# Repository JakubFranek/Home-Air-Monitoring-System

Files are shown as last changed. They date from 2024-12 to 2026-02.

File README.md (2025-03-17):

# Home Air Monitoring System

**Home Air Monitoring System (HAMS)** is my personal hardware & embedded software development project designed to monitor indoor and outdoor air quality in my home.

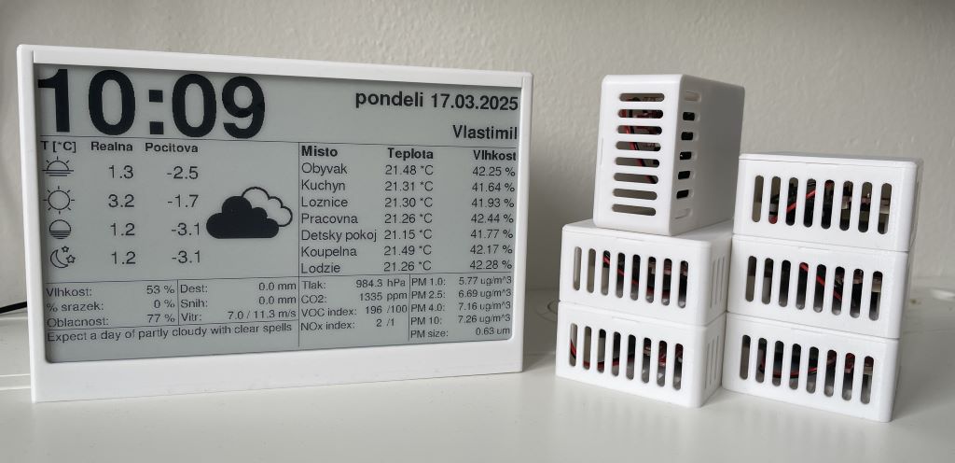
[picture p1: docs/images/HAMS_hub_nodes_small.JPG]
HAMS hub and nodes


## Overview

The system consists of a [**central hub**](./docs/hub.md) and [**six wireless sensor nodes**](./docs/node.md) to measure:

- Temperature
- Relative Humidity
- Atmospheric Pressure
- Particulate Matter
- Volatile Organic Compounds (VOCs)
- NOₓ
- CO₂

## System Components

- **Central Hub**
   - **ESP32-based**; mains-powered.
   - Connects to the internet for weather updates and time synchronization via SNTP.
   - Displays real-time measurements on a 7.5" 800x480 e-ink screen with a 1 minute refresh rate.
   - Contains sensors for all previously listed quantities.
   - Screen-sized 3D-printed enclosure (estimated 175 mm x 92.65 mm x 120 mm).

- **Sensor Nodes**
   - **STM32-based** and battery-powered, optimized for low power consumption and long battery life.
   - Equipped with temperature and humidity sensors only, with optional hardware support for one more sensor.
   - Transmit data to the hub every minute using nRF24 radio modules.
   - Minimalistic and visually non-intrusive 3D-printed case with a small form factor (estimated 81 mm x 58 mm x 28 mm).

## Sensors

- **SHT40**
   - Temperature and humidity sensor from Sensirion.
   - Used in the central hub and sensor nodes.
   - Temperature accuracy: ±0.2 °C
   - Humidity accuracy: ±1.8 %RH
- **SCD41**
   - CO2 sensor from Sensirion.
   - Used in the central hub.
   - CO2 accuracy: ±50 ppm ± 5.0 %m.v. (depending on range)
- **SGP41**
   - VOC and NOx gas index sensor from Sensirion.
   - Used in the central hub.
- **SPS30**
   - Particulate matter sensor from Sensirion.
   - Used in the central hub.
   - Accuracy: ±10 %
- **BME280**
   - Temperature, relative humidity and atmospheric pressure sensor from Adafruit.
   - Used in the central hub (for atmospheric pressure only).
   - Atmospheric pressure accuracy: ±1 hPa

## Documentation

- [Hub](./docs/hub.md)
- [Nodes](./docs/node.md)
- [SHT4x calibration](./docs/sht4x_calibration.md)

## Repository Structure

```plaintext
├── docs                         # Documentation for project setup, usage, etc.
├── utilities                    # Various auxiliary scripts, tools etc.
│   ├── sht_sensor_burn_in       # PlatformIO Arduino project for SHT40 sensor burn-in
│   └── sht_sensor_calibration   # PlatformIO Arduino project for SHT40 sensor calibration
├── hub
│   ├── hardware                 # PCB design and schematic for hub
│   ├── firmware                 # Firmware for the ESP32-based central hub
│   └── 3D_models                # 3D models for the hub's enclosure
├── node
│   ├── firmware                 # Firmware for the STM32-based sensor nodes
│   ├── hardware                 # PCB designs and schematics for nodes
│   └── 3D_models                # 3D models for the nodes' enclosures
├── README.md                    # Project overview (you are reading this now!)
└── TODO.md                      # Project task list

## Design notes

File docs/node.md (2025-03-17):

# HAMS node

HAMS node firmware for STM32L031K6 MCU is written in C and uses LL (low-layer) library as provided by ST Microelectronics, using no OS.

The nRF24 and SHT4x drivers are identical to the ones used in the ESP32 based HAMS hub, as all device drivers in this project are platform independent.

The MCU runs at 8 MHz (internal high speed oscillator), as the wake time is not determined by the MCU itself but rather by the sensor and the nRF24 module.

## Debug mode

Pressing the STATUS button on the PCB will toggle the debug mode on and off. When debug mode is on, the following effects occur:
1. debug log messages are sent via UART to the 2x7 1.27 mm pin header (accessible via ST-LINK V3 MINIE) at 38400 baud rate (because of this, the program runs slower and the wake time is longer)
2. green status LED is on (drawing up to 2 mA)
3. if there was any error since the last successfully completed loop cycle, the red error LED is on (drawing up to 2 mA)

Example UART output debug log messages are below:

```
[handle_state_sleep]woke up due to RTC: state = 0, app_status = 0, nrf24_status = 0, sht4x_status = 0, event = 4
[app_loop]: state = 1, app_status = 0, nrf24_status = 0, sht4x_status = 0, event = 0
[app_loop]: state = 2, app_status = 0, nrf24_status = 0, sht4x_status = 0, event = 0
[app_loop]: state = 3, app_status = 0, nrf24_status = 0, sht4x_status = 0, event = 0
[app_loop]: state = 4, app_status = 0, nrf24_status = 0, sht4x_status = 0, event = 0
[app_loop]: state = 0, app_status = 0, nrf24_status = 0, sht4x_status = 0, event = 0
[handle_state_sleep]entering sleep: state = 0, app_status = 0, nrf24_status = 0, sht4x_status = 0, event = 0
```

## Program flow

The application code structure is an event-driven Finite State Machine (FSM). The simplified flowchart is below.

The RTC peripheral is configured to wake up the node once every 60 seconds.

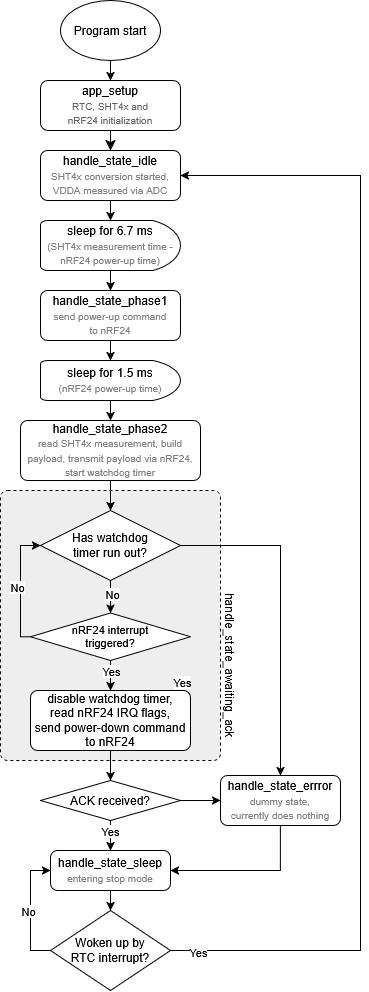
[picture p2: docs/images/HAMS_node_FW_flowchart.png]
HAMS node FW flowchart


## Logic analyzer waveforms

Typical period between stop mode exit and entrance is less than 15 ms.

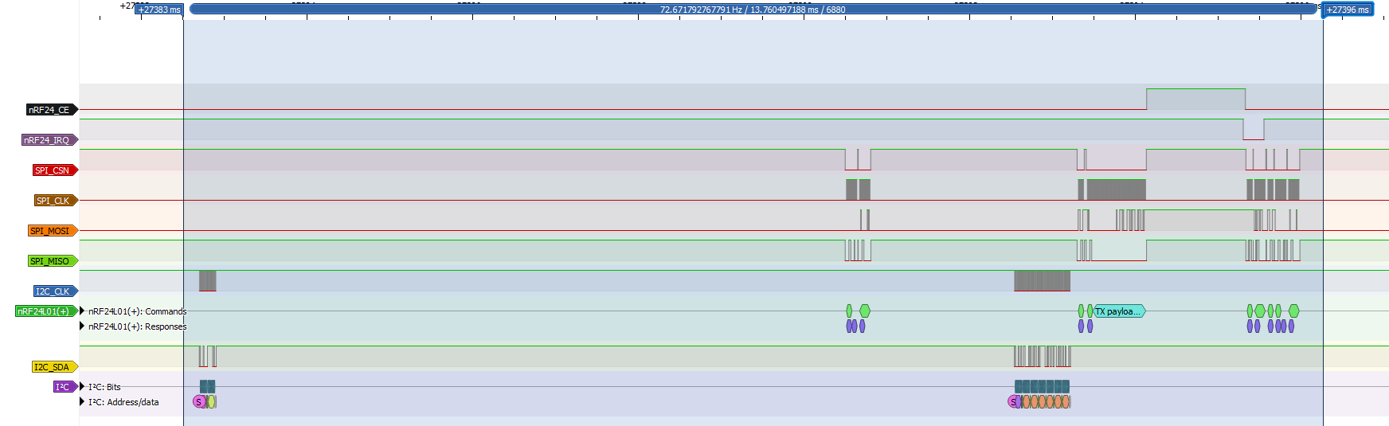
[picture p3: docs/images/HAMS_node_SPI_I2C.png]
HAMS node logic analyzer waveforms


## Batteries and power consumption

The nodes are powered via CR2032 batteries, with a nominal voltage of 3 Volt and nominal capacity of 210 mAh.

Typical current draw in stop mode has been measured to be from 1.8 to 2.5 uA, where cca half of the consumption is due to MCU and the other half is due to the nRF24 module (SHT4x current in power down is typically 80 nA per datasheet).

To calculate average power consumption, let us make the following conservative assumptions:
- MCU draws 5 mA when not in stop mode
- SHT4x draws 500 uA when measuring
- SHT4x takes up to 8.3 ms to measure (typical 6.9 ms per datasheet)
- nRF24 module draws 12 mA when transmitting (typical 11.3 mA per datasheet) and 400 uA when active but not transmitting (typical current draw during startup per datasheet)
- transmitting takes up to 1 ms (typical less than 0.5 ms)
- total wake time is 15 ms

Under the above assumptions, the average power consumption is 4.12 uA and the battery life is 5.8 years.

## Hardware

Case dimensions are: 81 mm (L) x 58 mm (W) x 30 mm (H). Printed by Prusa MK4S 3D-printer, using Prusament PLA Pristine White filament.

### PCB front
HAMS node PCB front

### PCB back
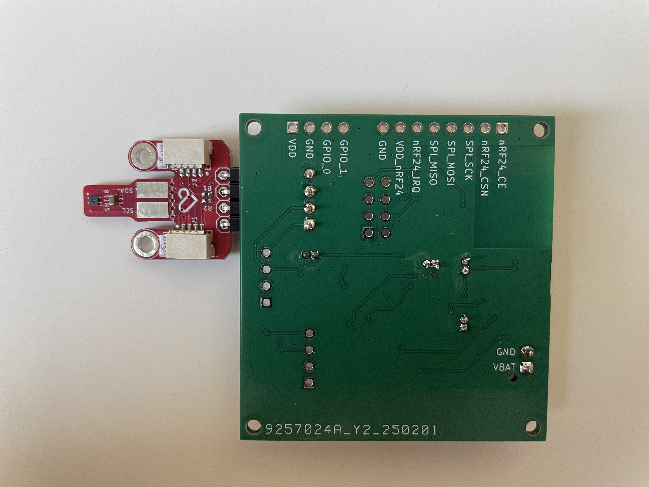
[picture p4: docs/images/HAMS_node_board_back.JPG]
HAMS node PCB back


### Disassembled
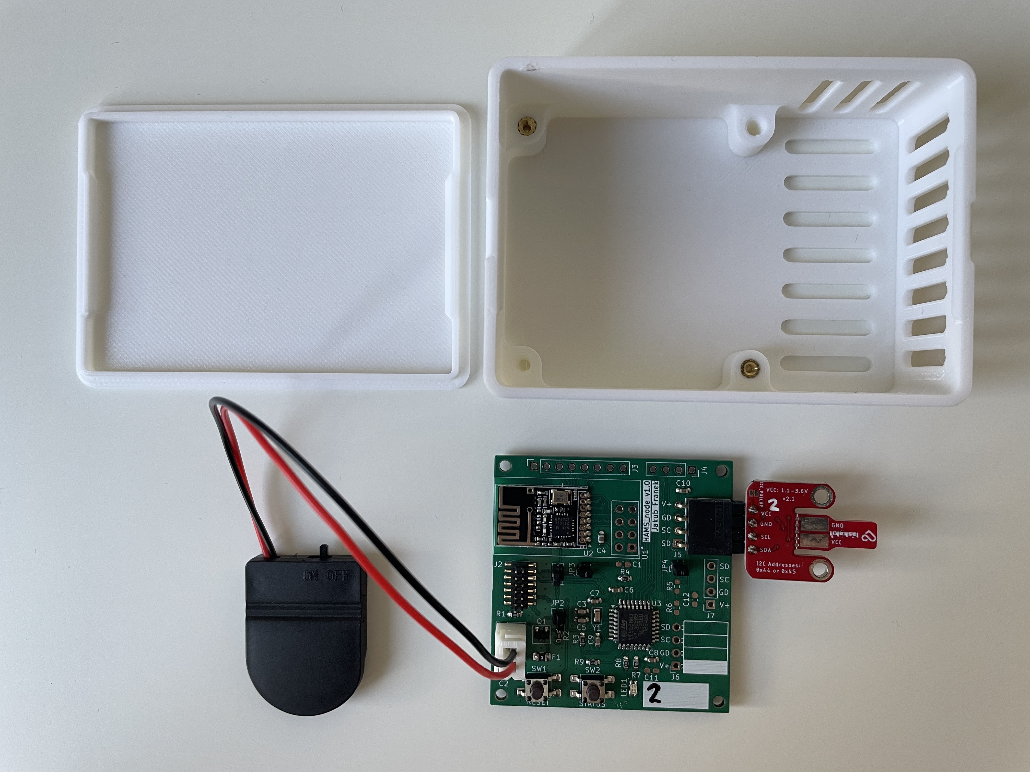
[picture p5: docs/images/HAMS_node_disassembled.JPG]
HAMS node disassembled


### Assembled box internals
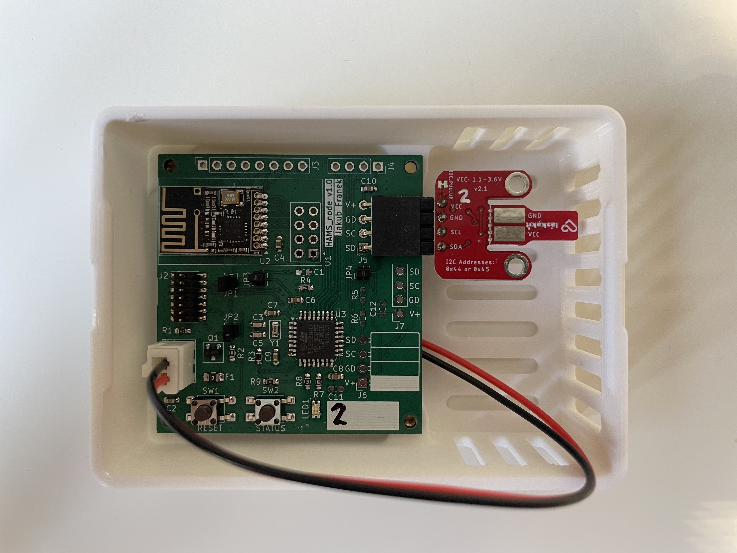
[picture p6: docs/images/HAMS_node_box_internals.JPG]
HAMS node box internals


### Assembled box front
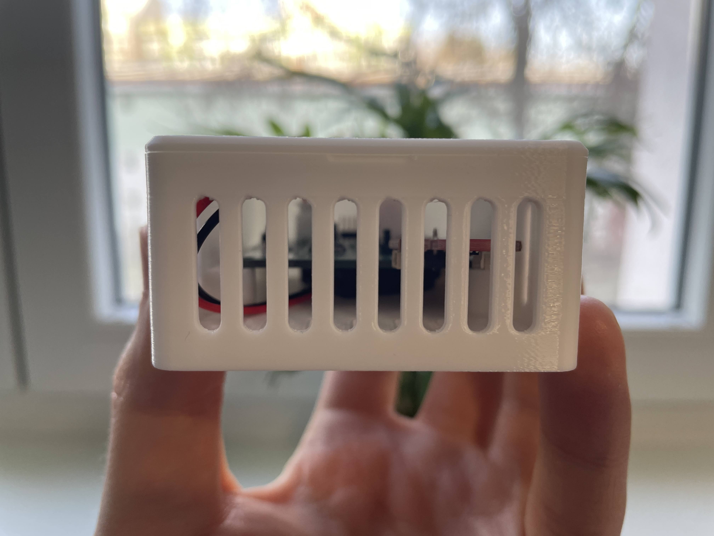
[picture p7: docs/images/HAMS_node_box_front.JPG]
HAMS node box front


### Assembled box bottom
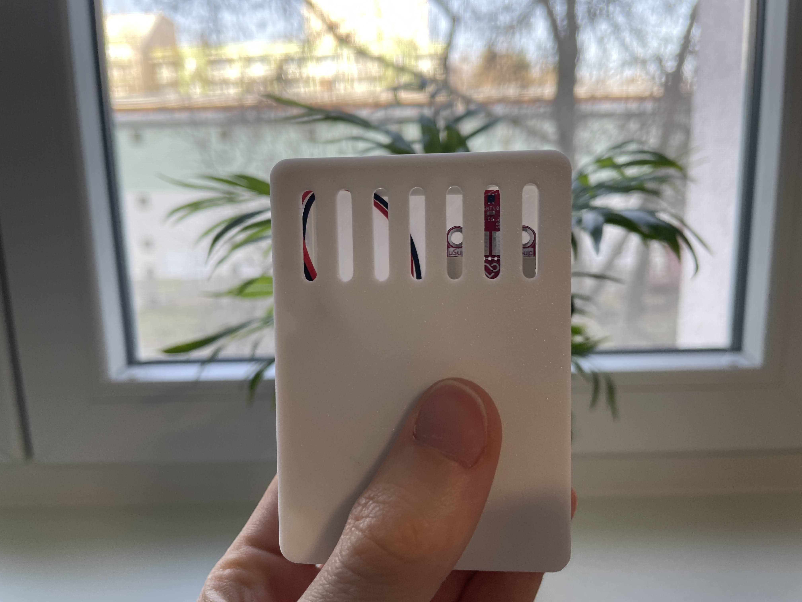
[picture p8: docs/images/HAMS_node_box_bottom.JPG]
HAMS node box bottom


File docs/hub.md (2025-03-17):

# HAMS hub

HAMS hub firmware for ESP32-S3 module is written in C and C++ and uses FreeRTOS as provided by Espressif.

The C++ language is used for the display-related code, as the CalEPD component (and its dependency Adafruit-GFX) are C++ based and utilize classes. Due to this the main file must also be a C++ file. Everything else is in plain C.

ESP32 is a chip with two CPU cores (the APP_CPU and the PRO_CPU). The PRO_CPU runs the task responsible for communication with the nRF24 radio module, whiile the APP_CPU handles everything else.

The nRF24 and SHT4x drivers are identical to the ones used in the STM32 based HAMS node, as all device drivers in this project are platform independent.

## Debug button

The debug button is located on the back of the HAMS hub enclosure, next to the reset button.

Pressing and releasing the button for more than 300 ms but less than 2 seconds will toggle the debug mode on and off. When debug mode is on, the display immediately changes to the [debug view](#debug-mode), which lists internal debug info.

Pressing and releasing the button after more than 2 seconds will schedule a SCD41 re-calibration (FRC). In the next SCD41 measurement cycle, the SCD41 will be recalibrated, assuming the current CO2 concentration is 425 ppm.

## Program flow

The application code flow is visualized in a simplified flowchart below.

Please note not all sensors take a reading every main loop cycle. For example SCD41 (CO₂ sensor) takes a reading once every 5 cycles / minutes.

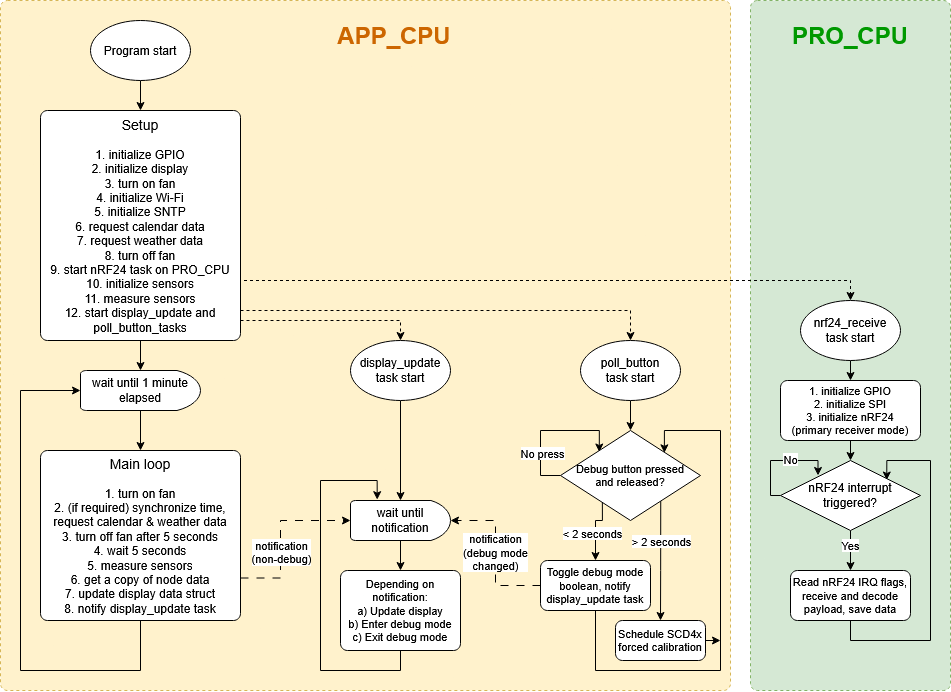
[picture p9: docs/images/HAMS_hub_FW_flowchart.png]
HAMS hub FW flowchart


## Hardware

Case dimensions are: 175 mm (W) x 92.85 mm (L) x 118 mm (H). Printed by Prusa MK4S 3D-printer, using Prusament PLA Pristine White filament.

### Front
HAMS hub front normal

### Debug mode
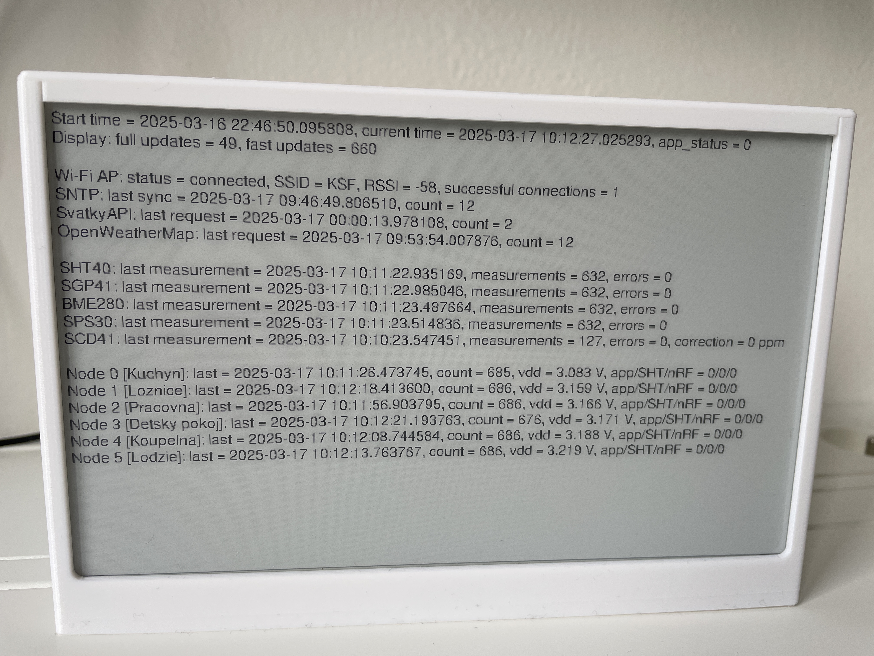
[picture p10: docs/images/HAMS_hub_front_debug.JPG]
HAMS hub front debug


### Start-up logging
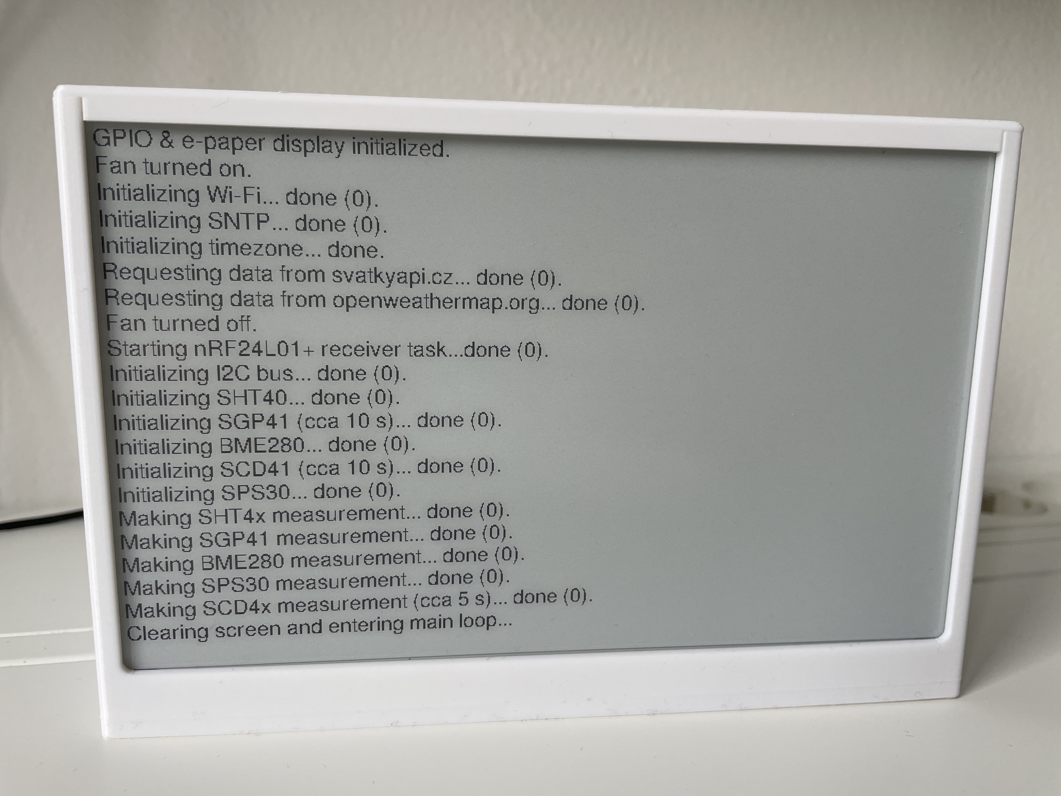
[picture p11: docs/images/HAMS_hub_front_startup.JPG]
HAMS hub front startup


### Side shot 1
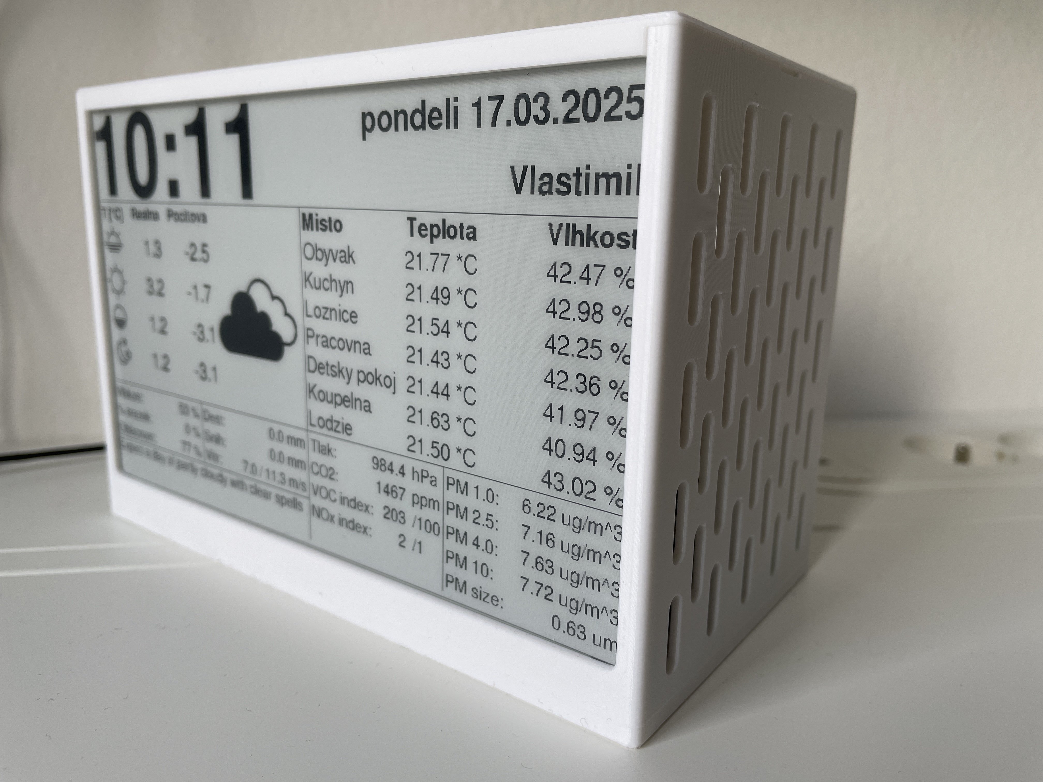
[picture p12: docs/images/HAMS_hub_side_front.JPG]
HAMS hub side front


### Side shot 2
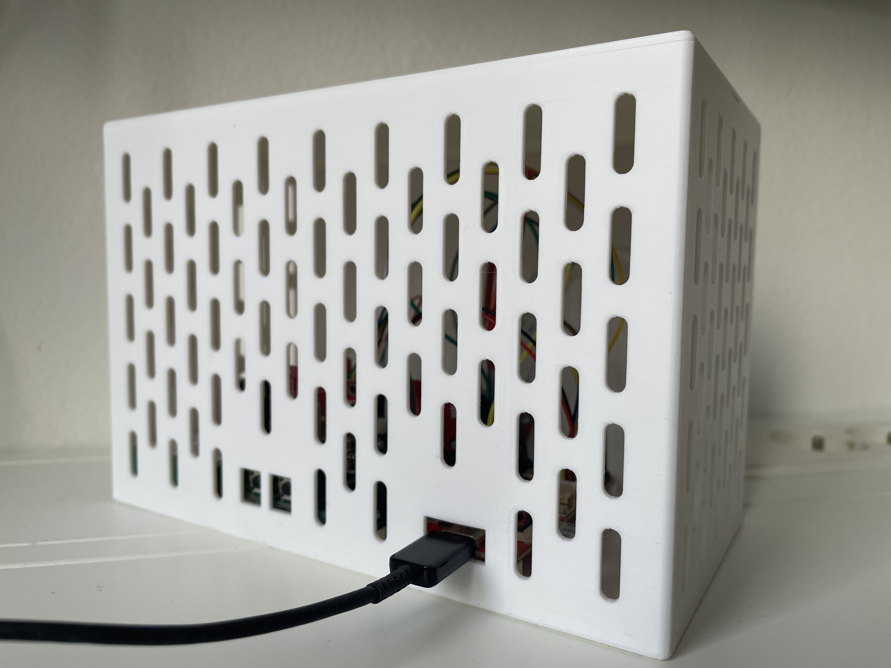
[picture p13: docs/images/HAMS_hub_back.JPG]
HAMS hub side back


### Internals
HAMS hub internals

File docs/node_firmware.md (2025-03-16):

# HAMS node firmware

HAMS node firmware for STM32L031K6 MCU is written in C and uses LL (low-layer) library as provided by ST Microelectronics, using no OS.

The nRF24 and SHT4x drivers are identical to the ones used in the ESP32 based HAMS hub, as all device drivers in this project are platform independent.

## Debug mode

Pressing the STATUS button on the PCB will toggle the debug mode on and off. When debug mode is on, the following effects occur:
1. debug log messages are sent via UART to the 2x7 1.27 mm pin header (accessible via ST-LINK V3 MINIE) at 38400 baud rate
2. green status LED is on
3. if there was any error since the last successfully completed loop cycle, the red error LED is on

## Program flow

The application code structure is an event-driven Finite State Machine (FSM). The simplified flowchart is below.

HAMS node FW flowchart

## Logic analyzer waveforms

Typical period between stop mode exit and entrance is less than 15 ms.

HAMS node logic analyzer waveforms

## Batteries and power consumption

The nodes are powered via CR2032 batteries, with a nominal voltage of 3 Volt and nominal capacity of 210 mAh.

Typical current draw in stop mode has been measured to be 1.8 to 2.5 uA.

To calculate average power consumption, let us make the following conservative assumptions:
- the MCU draws 5 mA when not in stop mode
- the nRF24 module draws 15 mA when transmitting
- transmitting takes up to 2 ms
- total wake time is 15 ms

Under the above assumptions, the average power consumption is 3.74 uA and the battery life is 6.4 years.

## Hardware

Case dimensions are: 81 mm (L) x 58 mm (W) x 30 mm (H). Printed by Prusa MK4S 3D-printer, using Prusament PLA Pristine White filament.

### PCB front
HAMS node PCB front

### PCB back
HAMS node PCB back

### Disassembled
HAMS node disassembled

### Assembled box internals
HAMS node box internals

### Assembled box front
HAMS node box front

### Assembled box bottom
HAMS node box bottom

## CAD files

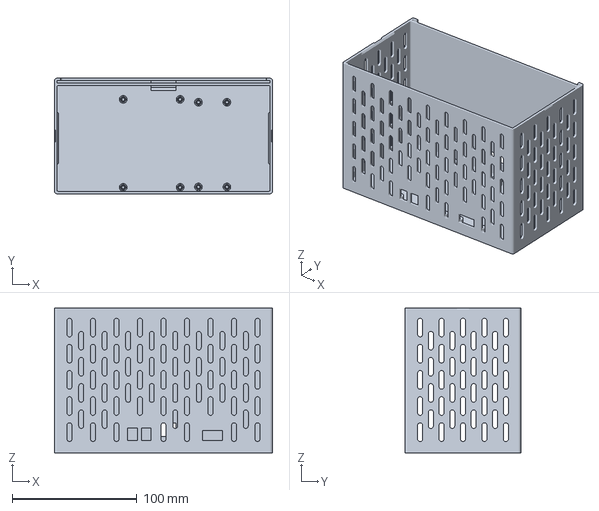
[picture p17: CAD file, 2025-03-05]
hub/3D_models/HAMS_hub_case.3mf
175.0 x 92.8 x 116.0 mm

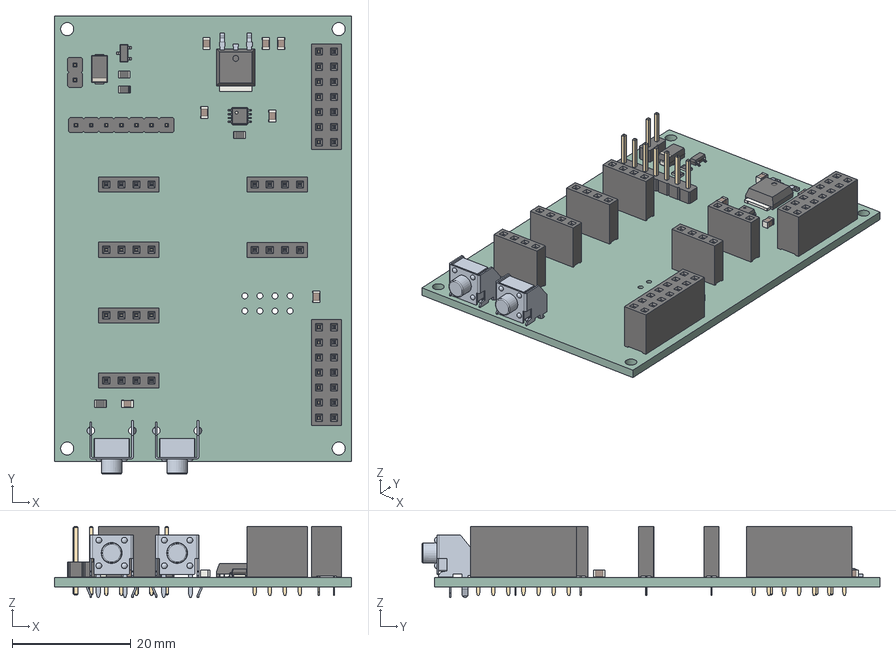
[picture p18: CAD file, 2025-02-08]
hub/hardware/HAMS_hub/HAMS_hub.step
50.0 x 77.1 x 12.0 mm
SOT_23
root x 2
PinSocket_2x07_P2.54mm_Vertical x 2
R_0805_2012Metric x 4
PinSocket_1x04_P2.54mm_Vertical x 6
PinHeader_1x02_P254mm_Vertical
C_0805_2012Metric x 7
SSOP_8_295x28mm_P065mm
D_SMA
PinHeader_1x07_P254mm_Vertical
CQ assembly
HAMS_hub_PCB

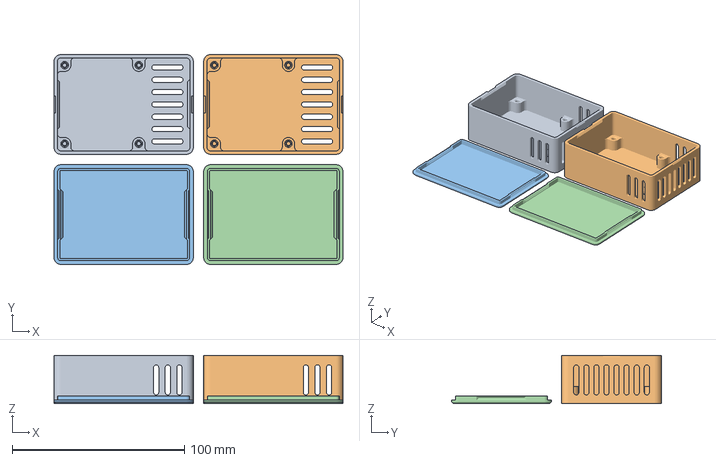
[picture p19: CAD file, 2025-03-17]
node/3D_models/HAMS_node_case_small_x2.3mf
168.0 x 122.0 x 28.0 mm
HAMS_node_case_small.stl
HAMS_node_case_small_cover.stl

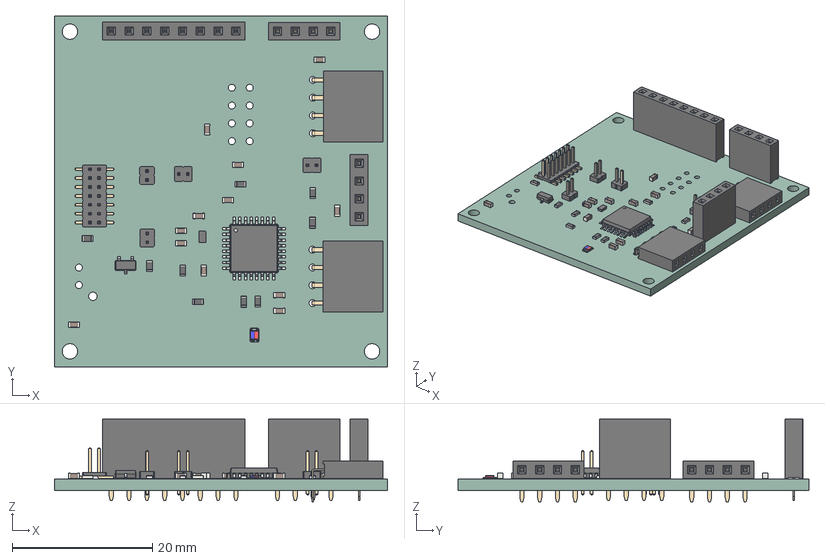
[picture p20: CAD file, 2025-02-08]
node/hardware/HAMS_node/HAMS_node.step
47.5 x 50.0 x 11.8 mm
PinHeader_1x02_P127mm_Vertical x 4
C_0603_1608Metric x 12
MicroCrystal_CM9V_T1A
R_0603_1608Metric x 9
PinSocket_1x04_P2.54mm_Horizontal x 2
PinSocket_1x04_P2.54mm_Vertical x 2
LQFP_32_7x7mm_P08mm
APHBM2012QBDSURKC
SOT_23
PinSocket_1x08_P2.54mm_Vertical
PinHeader_2x07_P127mm_Vertical_SMD
HAMS_node_PCB

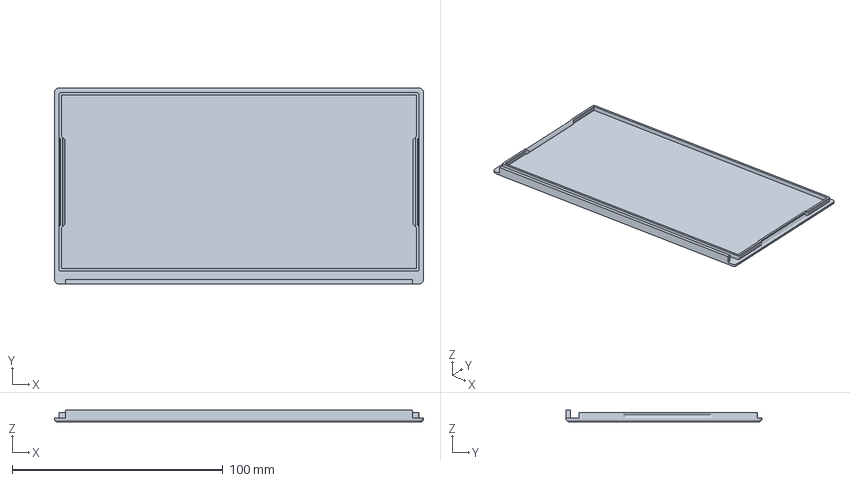
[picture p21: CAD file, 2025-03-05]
hub/3D_models/HAMS_hub_cover.3mf
175.0 x 92.8 x 5.80 mm

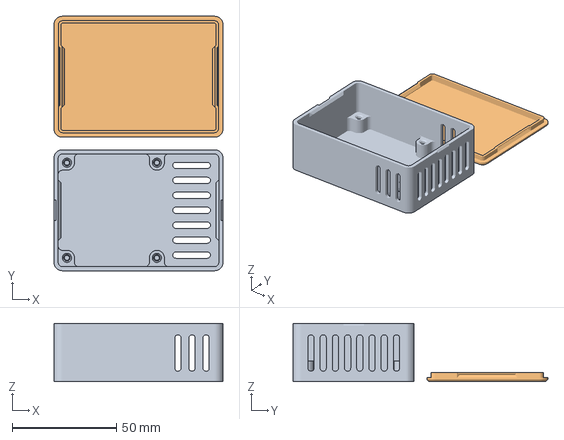
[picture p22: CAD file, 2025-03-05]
node/3D_models/HAMS_node_case_small.3mf
81.0 x 122.0 x 28.0 mm
HAMS_node_case_small.stl
HAMS_node_case_small_cover.stl

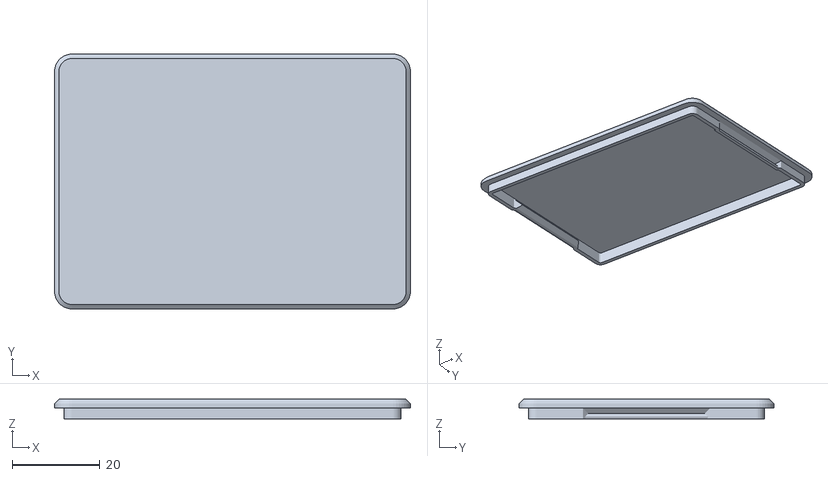
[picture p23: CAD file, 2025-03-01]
node/3D_models/HAMS_node_case_small_cover.stl
81.0 x 58.0 x 4.50

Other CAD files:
hub/3D_models/HAMS_hub_cover.stl
node/3D_models/HAMS_node_case_small.stl

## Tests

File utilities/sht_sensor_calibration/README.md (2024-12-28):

# Temperature & Relative Humidity Sensor Calibration

The purpose of this PlatformIO-based Arduino Uno project is to take temperature & relative humidity readings using many sensors, some which will be used in the HAMS hub and nodes, in order to calibrate them.

The measured data is sent via UART to the PC serial monitor, as well as displayed on a 20x4 alphanumeric LCD display, which is useful when the calibration setup is in an airtight transparent box, powered by a battery.

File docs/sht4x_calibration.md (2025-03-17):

# SHT4x reconditioning and calibration

The Sensirion SHT4x temperature and humidity sensors are calibrated in the factory. However, during assembly their accuracy is negatively affected by volatile organic compounds (VOCs). This impacts humidity measurement the most.

The image below shows a table. The numbered SHT40 sensors are clearly contaminated as they all report 6-9 % higher relative humidity than others.

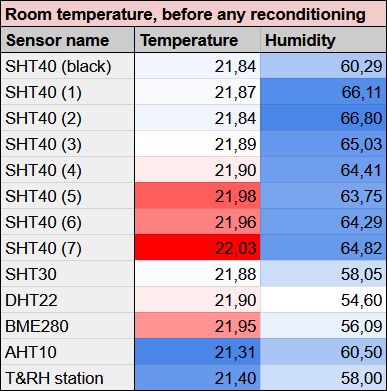
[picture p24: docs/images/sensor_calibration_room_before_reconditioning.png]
Sensor measurements, room, before reconditioning


Reconditioning has been performed using the on-chip heater, using [this a Arduino PlatformIO program](../utilities/sht_sensor_burn_in/src/main.cpp). As shown in the image below, the systematic offset decreased to cca 3-4 %, but some remanent offset remained nonetheles. While most of the sensors achieved self-reported temperature higher than 100 °C during the reconditioning, some sensors were not able to reach temperature higher than 85 °C.

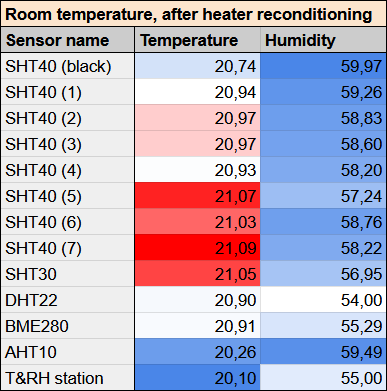
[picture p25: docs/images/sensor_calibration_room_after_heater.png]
Sensor measurements, room, after heater reconditioning


Final reconditioning has been performed using temperature forcing equipment (105 °C for cca 12 hours). The results are shown below.

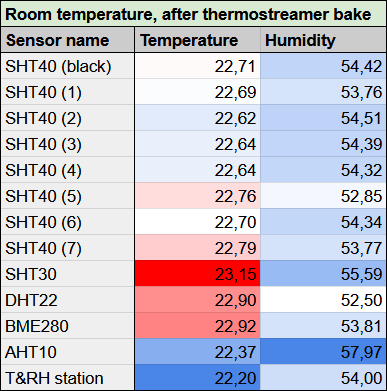
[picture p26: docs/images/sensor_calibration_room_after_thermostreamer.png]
Sensor measurements, room, after thermostreamer


To verify accuracy, the sensors were placed in a transparent airtight box and driven by [another Arduino PlatformIO program](../utilities/sht_sensor_calibration/src/main.cpp) powered from a powerbank. A bowl with a salt solution has been placed inside the box to produce known humidity (NaCl for 75 % and MgCl2 for 33 %). The measured quantities have been read from an LCD screen inside the box. 

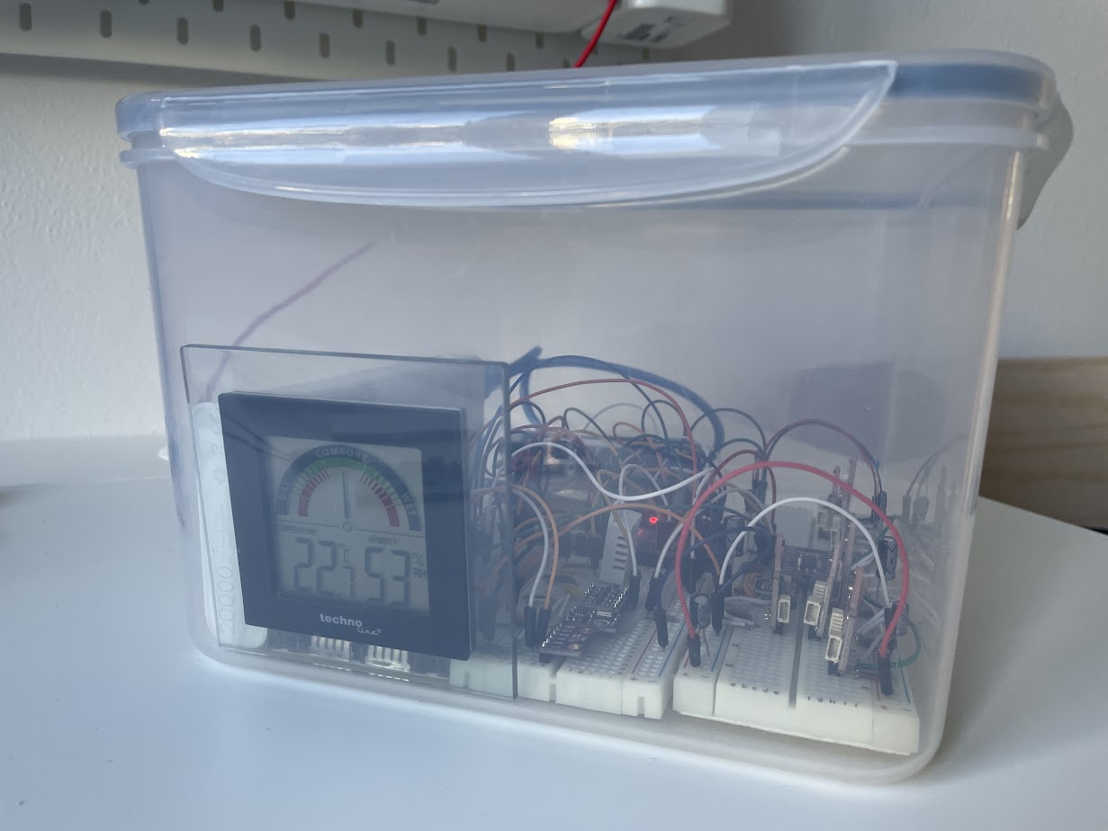
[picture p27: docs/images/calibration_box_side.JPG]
Calibration box, side


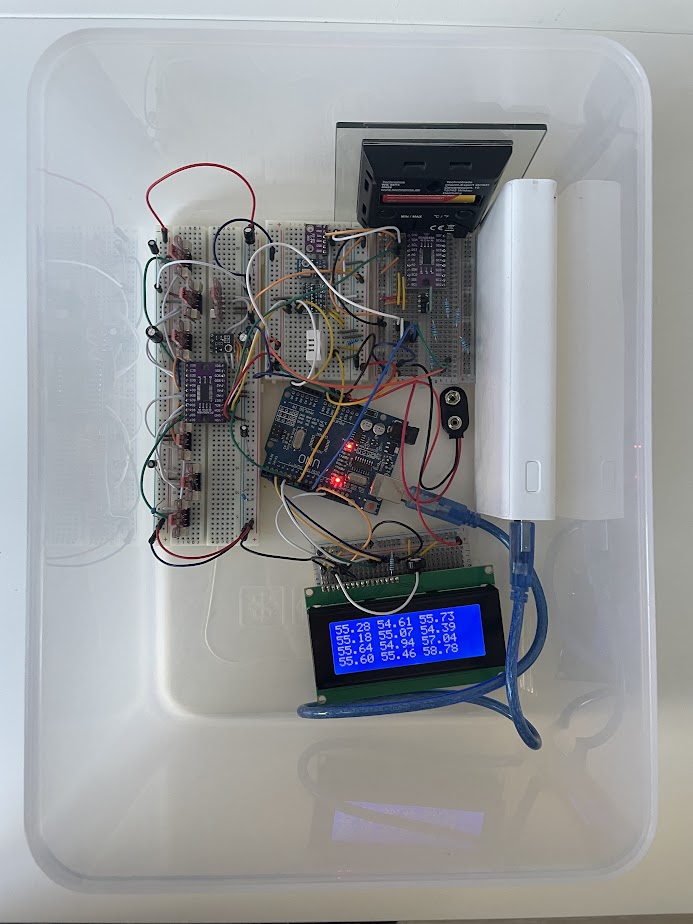
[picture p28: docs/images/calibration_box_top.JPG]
Calibration box, top


The results are shown below.

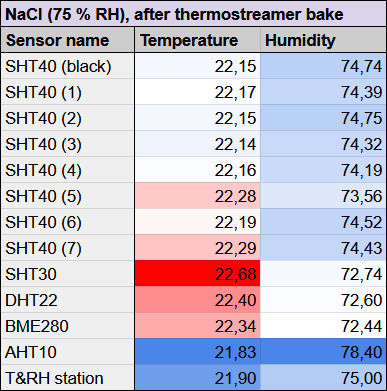
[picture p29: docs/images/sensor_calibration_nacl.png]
Sensor measurements, NaCl


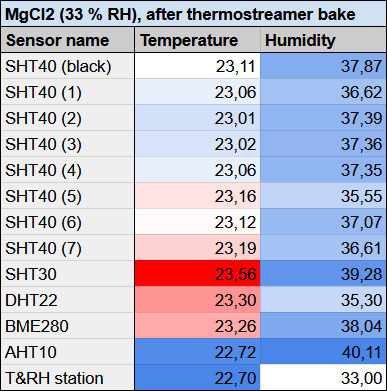
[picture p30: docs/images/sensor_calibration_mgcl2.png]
Sensor measurements, MgCl2


The NaCl measurements show that the sensors are undervaluing the relative humidity on average by less than 1 % (with the exception of sensor no.5), while the during the MgCl2 measurements the sensors overvalued the humidity by around 4 %. This remaining error has to be calibrated out in post-processing code (currently not implemented).

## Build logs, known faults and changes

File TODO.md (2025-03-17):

# Task list <!-- omit from toc -->

This is a task list for the HAMS project.

## Contents <!-- omit from toc -->
- [Work in progress](#work-in-progress)
- [To do](#to-do)
- [Backlog](#backlog)
- [Done](#done)

## Work in progress

## To do

## Backlog

- [ ] Hub firmware
    - [ ] Upload data from hub to Google Sheets or elsewhere online
    - [ ] Replace Adafruit_GFX with C-based graphical library to remove C++ altogether
    - [ ] Software calibration of SHT4x measurements
    - [ ] Turn SPS30 off after measurements to limit fan noise
- [ ] Node firmware
    - [ ] Support for SCD41 (possibly with MCU-driven ASC to minimize consumption)
    - [ ] Better error handling (nRF24 transmission of error codes even if FSM steps fail before nRF24 transmit step)
- [ ] Recalibrate SHT4x sensors

## Done

- [x] Node firmware v0.1
    - [x] Test firmware components in separate projects
        - [x] [Create and test nRF24L01+ driver](https://github.com/JakubFranek/STM32/tree/master/NUCLEO-L031K6/nRF24L01p_TX_RX_L031K6_LL)
        - [x] [Create and test SHT40 driver, incl. utilizing dedicated HW for CRC verification](https://github.com/JakubFranek/STM32/tree/master/NUCLEO-L031K6/SHT40_L031K6_LL) 
        - [x] [Test stop mode (incl. current consumption measurement)](https://github.com/JakubFranek/STM32/tree/master/NUCLEO-L031K6/Stop_mode_L031K6_LL)
        - [x] [Test ADC usage for supply voltage measurement](https://github.com/JakubFranek/STM32/tree/master/NUCLEO-L031K6/ADC_LL_L031K6)
        - [x] [Test scheduled wake-up from low power mode using RTC](https://github.com/JakubFranek/STM32/tree/master/NUCLEO-L031K6/RTC_wakeup_L031K6_LL)
    - [x] [Assemble all firmware components into one codebase](https://github.com/JakubFranek/Home-Air-Monitoring-System/tree/master/node/firmware/STM32L031K6)

- [x] Hub firmware v0.1
    - [x] Test firmware components in separate projects
        - [x] [Create and test SGP41 driver](https://github.com/JakubFranek/ESP32/tree/master/ESP-ink/I2C_SGP41)
        - [x] [Create and test SPS30 driver](https://github.com/JakubFranek/ESP32/tree/master/ESP-ink/I2C_SPS30)
        - [x] [Test nRF24L01+ driver (RX mode), incl. IRQ handling](https://github.com/JakubFranek/ESP32/tree/master/ESP-ink/nRF24L01p_RX)
        - [x] [Test SHT40 driver](https://github.com/JakubFranek/ESP32/tree/master/ESP-ink/I2C_SHT40)
        - [x] [Create and test SCD41 driver](https://github.com/JakubFranek/ESP32/tree/master/ESP-ink/I2C_SCD41)
        - [x] [Create and test BME280 driver](https://github.com/JakubFranek/ESP32/tree/master/ESP-ink/I2C_BME280)
        - [x] [Test 5 Volt fan control via GPIO](https://github.com/JakubFranek/ESP32/tree/master/ESP-ink/Fan_Switch)
        - [x] [Test WiFi connection](https://github.com/JakubFranek/ESP32/tree/master/Examples/station)
        - [x] [Test RTC time synchronization using SNTP](https://github.com/JakubFranek/ESP32/tree/master/Examples/sntp)
        - [x] [Combine WiFi connection and SNTP time sync into one code](https://github.com/JakubFranek/ESP32/tree/master/ESP-ink/WIFI_SNTP)
        - [x] Create e-ink display driver
            - [x] Determine best graphical library to use (Adafruit_GFX)
            - [x] Determine best driver to use ([customized CalEPD](https://github.com/JakubFranek/ESP32/tree/master/ESP-ink/Epaper_GDEY029T94_CalEPD_Demo))
            - [x] [Create and test GDEY075T7 driver](https://github.com/JakubFranek/ESP32/tree/master/ESP-ink/Epaper_GDEY075T7_CalEPD_Demo)
                - [x] Add support for full partial display refresh
                - [x] Test drawing a bitmap image
        - [x] [Get and parse current name day using HTTPS API](https://github.com/JakubFranek/ESP32/tree/master/ESP-ink/API_svatkyapicz)
        - [x] [Get and parse openweathermap.org weather forecast using HTTPS API](https://github.com/JakubFranek/ESP32/tree/master/ESP-ink/API_openweathermap)
    - [x] Design display interface
        - [x] Create display interface layout ([implemented in GDEY075T7 test project](https://github.com/JakubFranek/ESP32/tree/master/ESP-ink/Epaper_GDEY075T7_CalEPD_Demo))
        - [x] [Prepare a set of weather icon byte arrays for openweatherapi weather codes](https://github.com/JakubFranek/ESP32/blob/master/ESP-ink/Epaper_GDEY075T7_CalEPD_Demo/main/weather_icons.h)
        - [x] [Prepare a set of small morning / day / eve / night icons for temperatures](https://github.com/JakubFranek/ESP32/blob/master/ESP-ink/Epaper_GDEY075T7_CalEPD_Demo/main/time_of_day_icons.h)
    - [x] [Assemble all firmware components together into one codebase](https://github.com/JakubFranek/Home-Air-Monitoring-System/tree/master/hub/firmware)
        - [x] Implement e-ink display driver
        - [x] Implement WiFi connectivity
        - [x] Implement SNTP
        - [x] Implement svatkyapi.cz requests
        - [x] Implement openweathermap.org requests
        - [x] Implement SHT40 driver
        - [x] Implement SCD41 driver
        - [x] Implement SGP41 driver
        - [x] Implement SPS30 driver
        - [x] Implement BME280 driver
        - [x] Implement fan control
        - [x] Implement nRF24L01+ driver
        - [x] Display sensor data
        - [x] Display weather data
        - [x] Display startup sequence debug info
        - [x] Implement node timestamp checking
        - [x] Implement 24h minimum temperature logic for particular node
        - [x] Implement logic for long holiday names
        - [x] Implement debug display view based on GPIO button toggle
        - [x] Clean up code
        - [x] Show sensor status codes in debug mode
  
- [x] Node firmware
    - [x] Handle fault where nRF24 does not activate IRQ after transmitting
    - [x] Update SHT4x drivers (reuse better hub versions)
    - [x] Update nRF24 drivers (reuse better hub versions)
    - [x] Add comments / function documentation to app.c and important code elsewhere
    - [x] Add define for automatic retransmit delay based on NODE_ID
    - [x] Send UART debug logs only when in debug mode

- [x] Hub hardware
    - [x] Decide which connector to use to provide 5 Volt power to ESPink, SCD41, SPS30 and fan (ESPink hacked to provide 5 Volt power out of VIN pin)
    - [x] Hub sensor board schematic
        - [x] Add SPI & I2C debug headers
    - [x] Order PCBs
    - [x] Order components
    - [x] Hub 3D enclosure
        - [x] determine layout of ESPink + sensors + fan + power connector board
        - [x] determine debug display button location
        - [x] design
        - [x] print
    - [x] Assemble hub PCB
    - [x] Test hub PCB
    - [x] Assemble hub enclosure

- [x] Test SCD41 CO2 measurement in open air (expected cca 400 ppm, got cca 1400 ppm - calibration is off... try to force ASC)

- [x] Hub firmware    
    - [x] Remove T 24h min from the display
    - [x] Remove "Sever" node, add "Detsky pokoj" node
    - [x] Add pressure correction to SCD41 measurements
    - [x] SCD41 force FRC via long debug button press 

- [x] Firmware: reprogram hub and nodes to 250 kbps data rate to increase range
- [x] Hub firmware: fix pressure units

- [x] Create documentation
    - [x] Document node software incl. flowchart
    - [x] Document hub software incl. FreeRTOS tasks and flowchart
    - [x] Photos
        - [x] Assembled node
        - [x] Assembled hub
        - [x] Hub display
        - [x] Hub debug display
        - [x] Hub + nodes photo
        - [x] Logic waveforms
    - [x] Add HAMS node current measurements
    - [x] Add enclosure dimension to hardware docs
    - [x] Document hub debug button

- [x] SHT40 sensor burn-in and calibration    
    - [x] [Create a burn-in program](https://github.com/JakubFranek/Home-Air-Monitoring-System/tree/master/utilities/sht_sensor_burn_in)
    - [x] Burn-in SHT40 sensors to remove VOC contaminants
    - [x] [Create a calibration program](https://github.com/JakubFranek/Home-Air-Monitoring-System/tree/master/utilities/sht_sensor_calibration)
    - [x] Calibrate SHT40 sensor humidity measurements using NaCl and MgCl salt solutions

- [x] Node hardware
    - [x] Node schematic
        - [x] QFP32 breakout board test (test programmability with ST-LINK V3 MINIE)
        - [x] decide whether to use LDO or not (decided to not use LDO, will be created as a separate board if needed)
        - [x] decide whether to support USB power supply as well (decided not to use USB, will be created as a separate board if needed)
        - [x] choose batteries & protection (CR2032 & LiFePO4)
        - [x] bring out SPI, I2C & SWD nodes for programming & debug
        - [x] bring out unused GPIO just in case
        - [x] implement supply current measurement jumpers
        - [x] draw schematic in KiCAD
        - [x] double check all connections
    - [x] Node PCB layout
    - [x] Order PCBs
    - [x] Order components
    - [x] Node 3D enclosure design
        - [x] design
        - [x] test print
        - [x] final print (6x)
    - [x] Node PCB assembly
    - [x] Fix battery holder crimping
    - [x] Flash nodes
    - [x] Test nodes
    - [x] Cover exterior nodes in protective plastic coating

- [x] Firmware: Change radio data rate to 250 kbps to increase range

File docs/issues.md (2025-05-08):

# Issues

This is a list of issues that have been observed during the project's deployment.

1. Node & hub communication sometimes hiccups and a few consecutive messages are not received by the hub
   - Affected nodes: all
   - Occurence: observed cca once per day
   - Suspect: nRF24 radio module (weak signal, low quality of Chinese knockoff modules), walls with metal rebars acting as radio reflectors
2. Some nodes experience very long term communication failures (duration of several hours or more)
    - Affected nodes: board no. 6 (balcony)
    - Occurence: observed once during the first three months of operation
    - Suspect: none (board no. 6 has been once again made operational for unknown reason)
3. Erroneous node message values are sometimes displayed
   - Temperatures of hundreds of degrees Celsius or relative humidities of hundreds of percents have been observed, as well as status codes in high tens or VDDAs of 70 Volts etc.
   - Often occurs at the same time as radio communication errors
   - There is no known source or sensible explanation for this as of yet... maybe extra CRC byte in nRF24 protocol would help?
   - Affected nodes: all
   - Occurence: observed cca once per month
   - Suspect: none

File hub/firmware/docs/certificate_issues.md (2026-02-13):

# ESP32 SSL Certificate Problem & Solutions

## The Problem

When making HTTPS requests to APIs (like svatkyapi.cz or openweathermap.org), the ESP32 was failing with this error:

```
E (21827) esp-tls-mbedtls: mbedtls_ssl_handshake returned -0x2700
I (21827) esp-tls-mbedtls: Failed to verify peer certificate!
E (21827) esp-tls: Failed to open new connection
E (21837) transport_base: Failed to open a new connection
E (21837) HTTP_CLIENT: Connection failed, sock < 0
```

### Root Cause

SSL/TLS certificates expire and get renewed regularly (typically every 3 months to 1 year). The embedded certificate in the ESP32 firmware was outdated and didn't match what the server was presenting.

**Key insight:** You need the FULL certificate chain (server cert → intermediate CA → root CA), not just the server's certificate. The ESP32 uses this chain to verify the server's identity.

---

## Solution 1: Manual Certificate Update (What We Did First)

### Steps:

1. **Download the full certificate chain:**
   ```bash
   cd /path/to/your/project/main/
   
   # Replace domain.com with your API domain
   openssl s_client -showcerts -servername domain.com -connect domain.com:443 </dev/null 2>/dev/null | sed -n '/BEGIN CERTIFICATE/,/END CERTIFICATE/p' > cert.pem
   ```

   Example for svatkyapi.cz:
   ```bash
   openssl s_client -showcerts -servername svatkyapi.cz -connect svatkyapi.cz:443 </dev/null 2>/dev/null | sed -n '/BEGIN CERTIFICATE/,/END CERTIFICATE/p' > svatkyapicz_cert.pem
   ```

2. **Verify you got all certificates:**
   ```bash
   grep -c "BEGIN CERTIFICATE" cert.pem
   ```
   Should output 2-3 (you need the full chain)

3. **Rebuild and flash:**
   ```bash
   idf.py build flash monitor
   ```

### Pros:
- Full control over which certificates are trusted
- Smaller firmware size (only includes needed certificates)

### Cons:
- **Must manually update every 3-12 months when certificates expire**
- Requires rebuilding and reflashing firmware
- Easy to forget until it breaks

---

## Solution 2: ESP-IDF Certificate Bundle (RECOMMENDED - What We Chose)

Use ESP-IDF's built-in bundle of root CA certificates that rarely change.

### Code Changes:

**In your API code (e.g., svatky_api.c):**

Add include:
```c
#include "esp_crt_bundle.h"
```

Change the HTTP client config from:
```c
esp_http_client_config_t config = {
    .url = url_buffer,
    .event_handler = _http_event_handler,
    .cert_pem = svatkyapicz_cert_pem_start,  // OLD
};
```

To:
```c
esp_http_client_config_t config = {
    .url = url_buffer,
    .event_handler = _http_event_handler,
    .crt_bundle_attach = esp_crt_bundle_attach,  // NEW
};
```

**In main/CMakeLists.txt:**

Add the required components:
```cmake
idf_component_register(SRCS "your_sources.c" ...
                    INCLUDE_DIRS "."
                    REQUIRES esp_http_client mbedtls esp-tls  # Add these
                    EMBED_TXTFILES "cert.pem")  # Can remove this line now
```

### Pros:
- **No manual certificate updates needed!**
- Works with any API that uses standard certificate authorities
- Certificates auto-renew on the server side without firmware changes

### Cons:
- Slightly larger firmware size (~10-20KB for the certificate bundle)
- Trusts all common CAs (less restrictive than pinning specific certs)

---

## When to Use Each Solution

**Use Certificate Bundle (Solution 2) if:**
- Your API uses standard SSL certificates from common CAs (Let's Encrypt, DigiCert, etc.)
- You want a "set it and forget it" solution
- The device will be deployed long-term without easy firmware updates

**Use Manual Certificates (Solution 1) if:**
- You need certificate pinning for extra security
- You're connecting to internal/self-signed certificates
- Firmware size is extremely constrained

---

## Quick Reference Commands

**Check certificate expiry:**
```bash
openssl x509 -in cert.pem -text -noout | grep -A 2 "Validity"
```

**Download fresh certificate chain:**
```bash
openssl s_client -showcerts -servername DOMAIN -connect DOMAIN:443 </dev/null 2>/dev/null | sed -n '/BEGIN CERTIFICATE/,/END CERTIFICATE/p' > cert.pem
```

**Verify certificate count:**
```bash
grep -c "BEGIN CERTIFICATE" cert.pem
```

---

## Troubleshooting

If you still get certificate errors after updating:

1. **Check ESP32's system time** - SSL certificates have validity dates
   - Look for SNTP sync messages in logs
   - Incorrect date/time will cause "certificate expired" errors

2. **Verify you have the full chain** - Should be 2-3 certificates, not just 1

3. **Check the domain matches** - Certificate must match the exact domain you're connecting to

4. **Try certificate bundle first** - Easier than manual certificate management

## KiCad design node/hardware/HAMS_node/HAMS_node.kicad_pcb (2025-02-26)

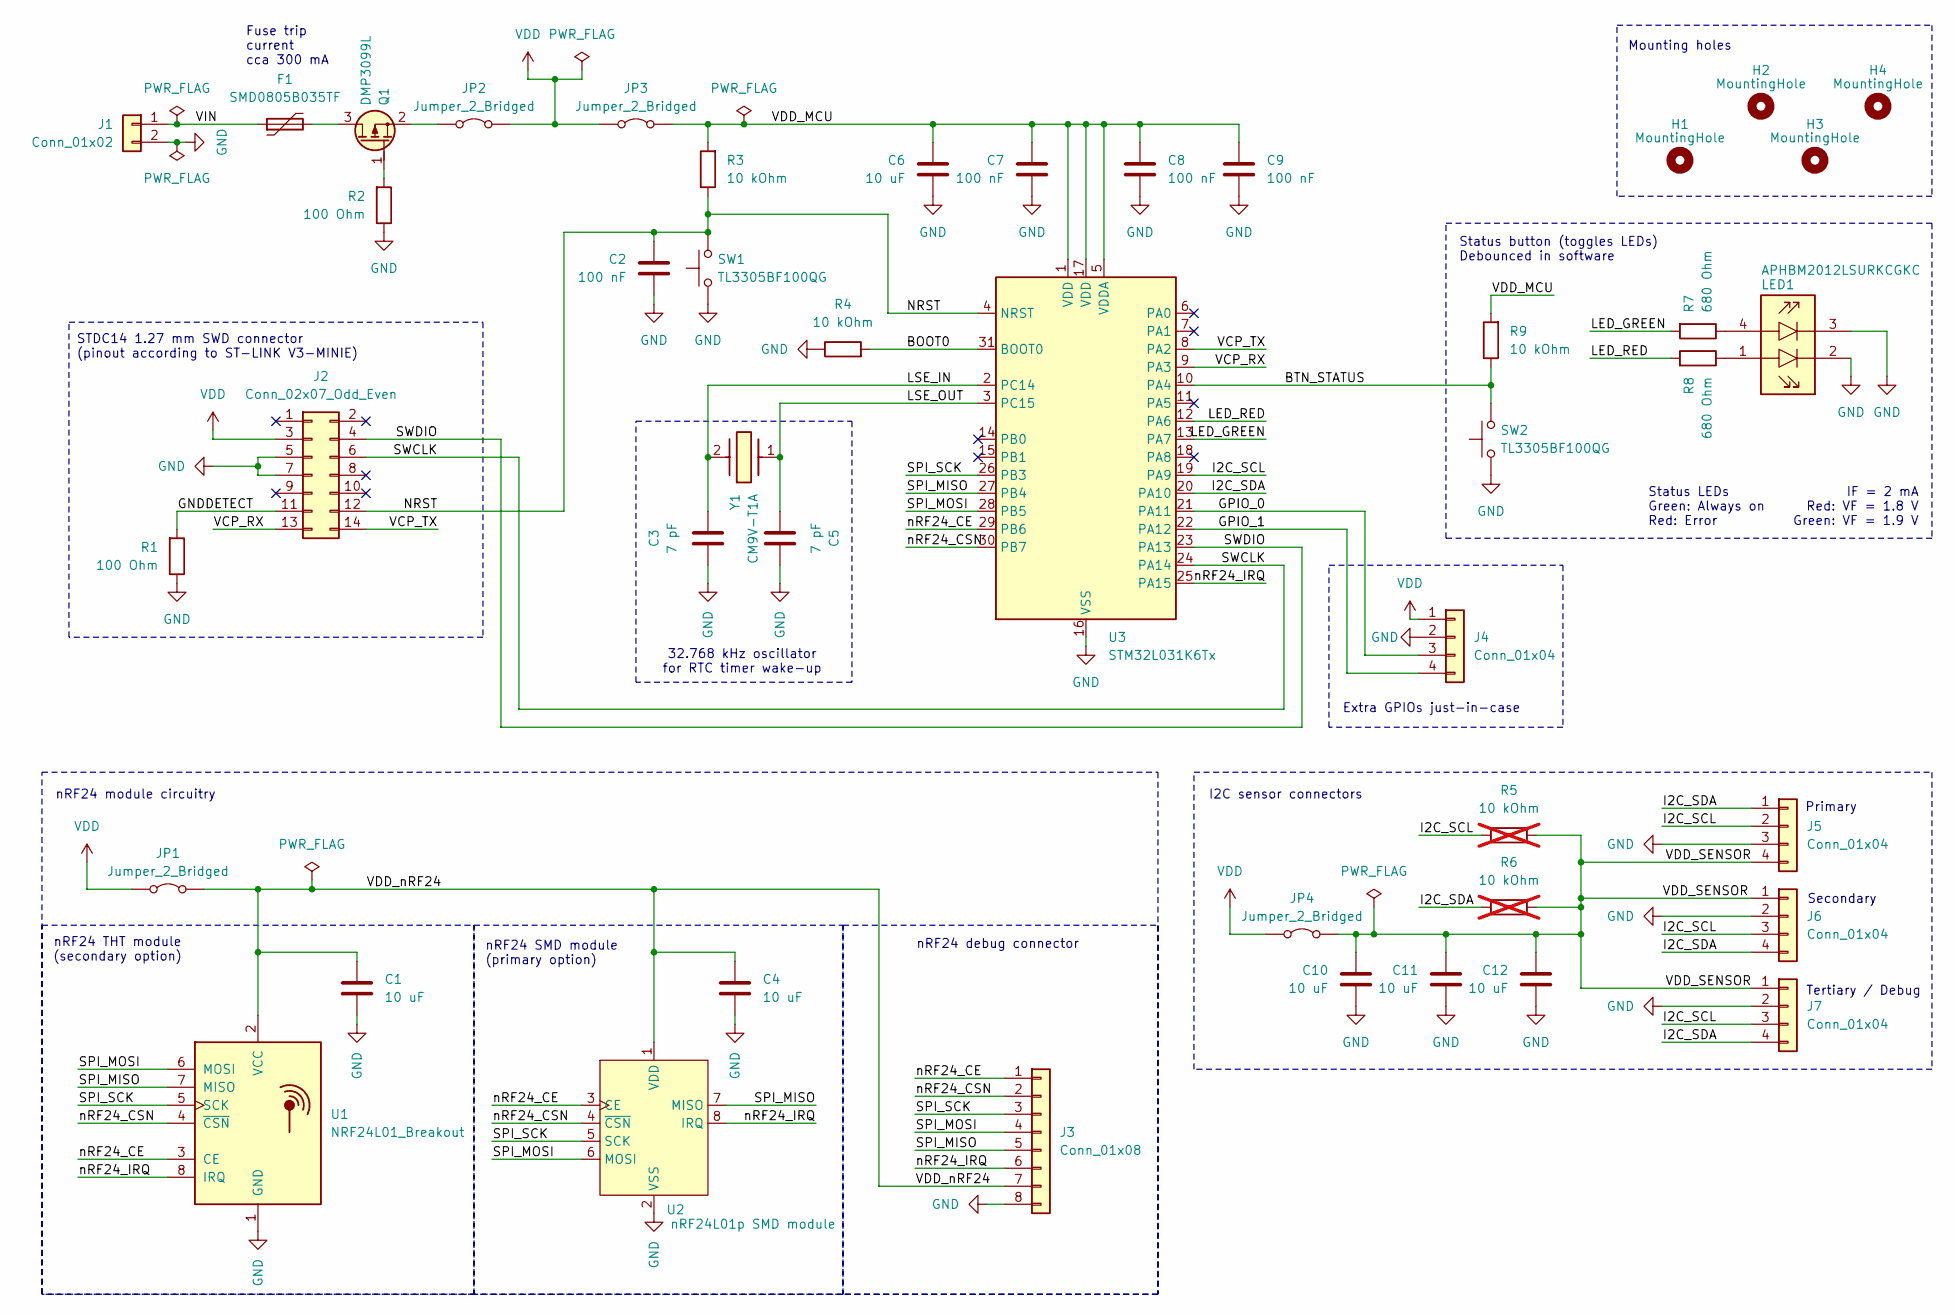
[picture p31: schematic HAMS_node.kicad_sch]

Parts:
C1, C4, C6, C10, C11, C12: 10 uF; C_0603_1608Metric_Pad1.08x0.95mm_HandSolder
C2, C7, C8, C9: 100 nF; C_0603_1608Metric_Pad1.08x0.95mm_HandSolder
C3, C5: 7 pF; C_0603_1608Metric_Pad1.08x0.95mm_HandSolder
F1: SMD0805B035TF; YAGEO_SMD0805_Fuse
H1, H2, H3, H4: MountingHole; MountingHole_2.2mm_M2_ISO7380
J1: Conn_01x02; JST_XH_B2B-XH-AM_1x02_P2.50mm_Vertical
J2: Conn_02x07_Odd_Even; PinHeader_2x07_P1.27mm_Vertical_SMD
J3: Conn_01x08; PinSocket_1x08_P2.54mm_Vertical
J4, J7: Conn_01x04; PinSocket_1x04_P2.54mm_Vertical
J5, J6: Conn_01x04; PinSocket_1x04_P2.54mm_Horizontal
JP1, JP2, JP3, JP4: Jumper_2_Bridged; PinHeader_1x02_P1.27mm_Vertical
LED1: APHBM2012LSURKCGKC; KPHBM2012QBDCGKC; Mouser Part Number 604-APHBM2012LSURKCG
Q1: DMP3099L; SOT-23
R1, R2: 100 Ohm; R_0603_1608Metric_Pad0.98x0.95mm_HandSolder
R3, R4, R9: 10 kOhm; R_0603_1608Metric_Pad0.98x0.95mm_HandSolder
R5, R6: 10 kOhm; R_0603_1608Metric_Pad0.98x0.95mm_HandSolder; not fitted
R7, R8: 680 Ohm; R_0603_1608Metric_Pad0.98x0.95mm_HandSolder
SW1, SW2: TL3305BF100QG; E-Switch_TL3305BF100QG_Tactile_SPST
U1: NRF24L01_Breakout; nRF24L01_Breakout
U2: nRF24L01p SMD module; nRF24L01p_SMD_module
U3: STM32L031K6Tx; LQFP-32_7x7mm_P0.8mm
Y1: CM9V-T1A; Crystal_SMD_MicroCrystal_CM9V-T1A-2Pin_1.6x1.0mm_BigPads; Mouser Part Number 428-202416-MC01

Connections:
/BOOT0: R4.2, U3.31 (BOOT0)
/BTN_STATUS: R9.1, SW2.2, U3.10 (PA4)
/GNDDETECT: J2.11, R1.2
/GPIO_0: J4.3, U3.21 (PA11)
/GPIO_1: J4.4, U3.22 (PA12)
/I2C_SCL: J5.2, J6.3, J7.3, R5.1, U3.19 (PA9)
/I2C_SDA: J5.1, J6.4, J7.4, R6.1, U3.20 (PA10)
/LED_GREEN: R7.2, U3.13 (PA7)
/LED_RED: R8.2, U3.12 (PA6)
/LSE_IN: C3.1, U3.2 (PC14), Y1.2 (X2)
/LSE_OUT: C5.1, U3.3 (PC15), Y1.1 (X1)
/NRST: C2.1, J2.12, R3.1, SW1.2, U3.4 (NRST)
/SPI_MISO: J3.5, U1.7 (MISO), U2.7 (MISO), U3.27 (PB4)
/SPI_MOSI: J3.4, U1.6 (MOSI), U2.6 (MOSI), U3.28 (PB5)
/SPI_SCK: J3.3, U1.5 (SCK), U2.5 (SCK), U3.26 (PB3)
/SWCLK: J2.6, U3.24 (PA14)
/SWDIO: J2.4, U3.23 (PA13)
/VCP_RX: J2.13, U3.9 (PA3)
/VCP_TX: J2.14, U3.8 (PA2)
/VDD_MCU: C6.1, C7.1, C8.1, C9.1, JP3.2 (B), R3.2, R9.2, U3.1 (VDD), U3.5 (VDDA), U3.17 (VDD)
/VDD_SENSOR: C10.1, C11.1, C12.1, J5.4, J6.1, J7.1, JP4.2 (B), R5.2, R6.2
/VDD_nRF24: C1.2, C4.2, J3.7, JP1.2 (B), U1.2 (VCC), U2.1 (VDD)
/VIN: F1.1, J1.1
/nRF24_CE: J3.1, U1.3 (CE), U2.3 (CE), U3.29 (PB6)
/nRF24_CSN: J3.2, U1.4 (~CSN), U2.4 (~CSN), U3.30 (PB7)
/nRF24_IRQ: J3.6, U1.8 (IRQ), U2.8 (IRQ), U3.25 (PA15)
GND: C1.1, C2.2, C3.2, C4.1, C5.2, C6.2, C7.2, C8.2, C9.2, C10.2, C11.2, C12.2, J1.2, J2.5, J2.7, J3.8, J4.2, J5.3, J6.2, J7.2, LED1.2 (CATHODE_RED), LED1.3 (CATHODE_GREEN), R1.1, R2.1, R4.1, SW1.1, SW2.1, U1.1 (GND), U2.2 (VSS), U3.16 (VSS), U3.32 (VSS)
unnamed: JP2.1 (A), Q1.2 (S)
unnamed: LED1.4 (ANODE_GREEN), R7.1
unnamed: LED1.1 (ANODE_RED), R8.1
unnamed: F1.2, Q1.3 (D)
unnamed: Q1.1 (G), R2.2
VDD: J2.3, J4.1, JP1.1 (A), JP2.2 (B), JP3.1 (A), JP4.1 (A)

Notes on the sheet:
nRF24 THT module (secondary option)
IF = 2 mA Red: VF = 1.8 V Green: VF = 1.9 V
nRF24 SMD module (primary option)
32.768 kHz oscillator for RTC timer wake-up
Mounting holes
Fuse trip current cca 300 mA
Status LEDs Green: Always on Red: Error
Secondary
nRF24 debug connector
Tertiary / Debug
Status button (toggles LEDs) Debounced in software
STDC14 1.27 mm SWD connector (pinout according to ST-LINK V3-MINIE)
Primary
Extra GPIOs just-in-case
I2C sensor connectors
nRF24 module circuitry

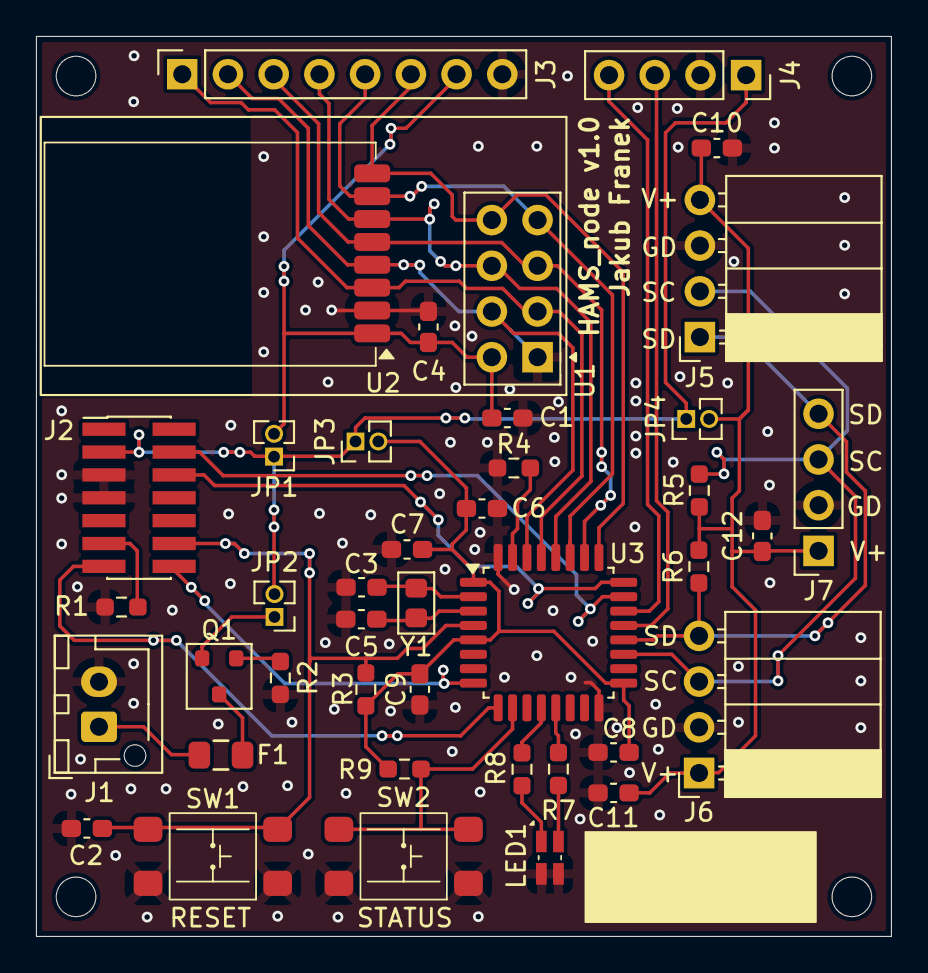
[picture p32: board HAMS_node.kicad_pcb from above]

Board: 2 copper layers, 47.5 x 50.0 mm, 45 parts (0 on the bottom side), 33 nets.

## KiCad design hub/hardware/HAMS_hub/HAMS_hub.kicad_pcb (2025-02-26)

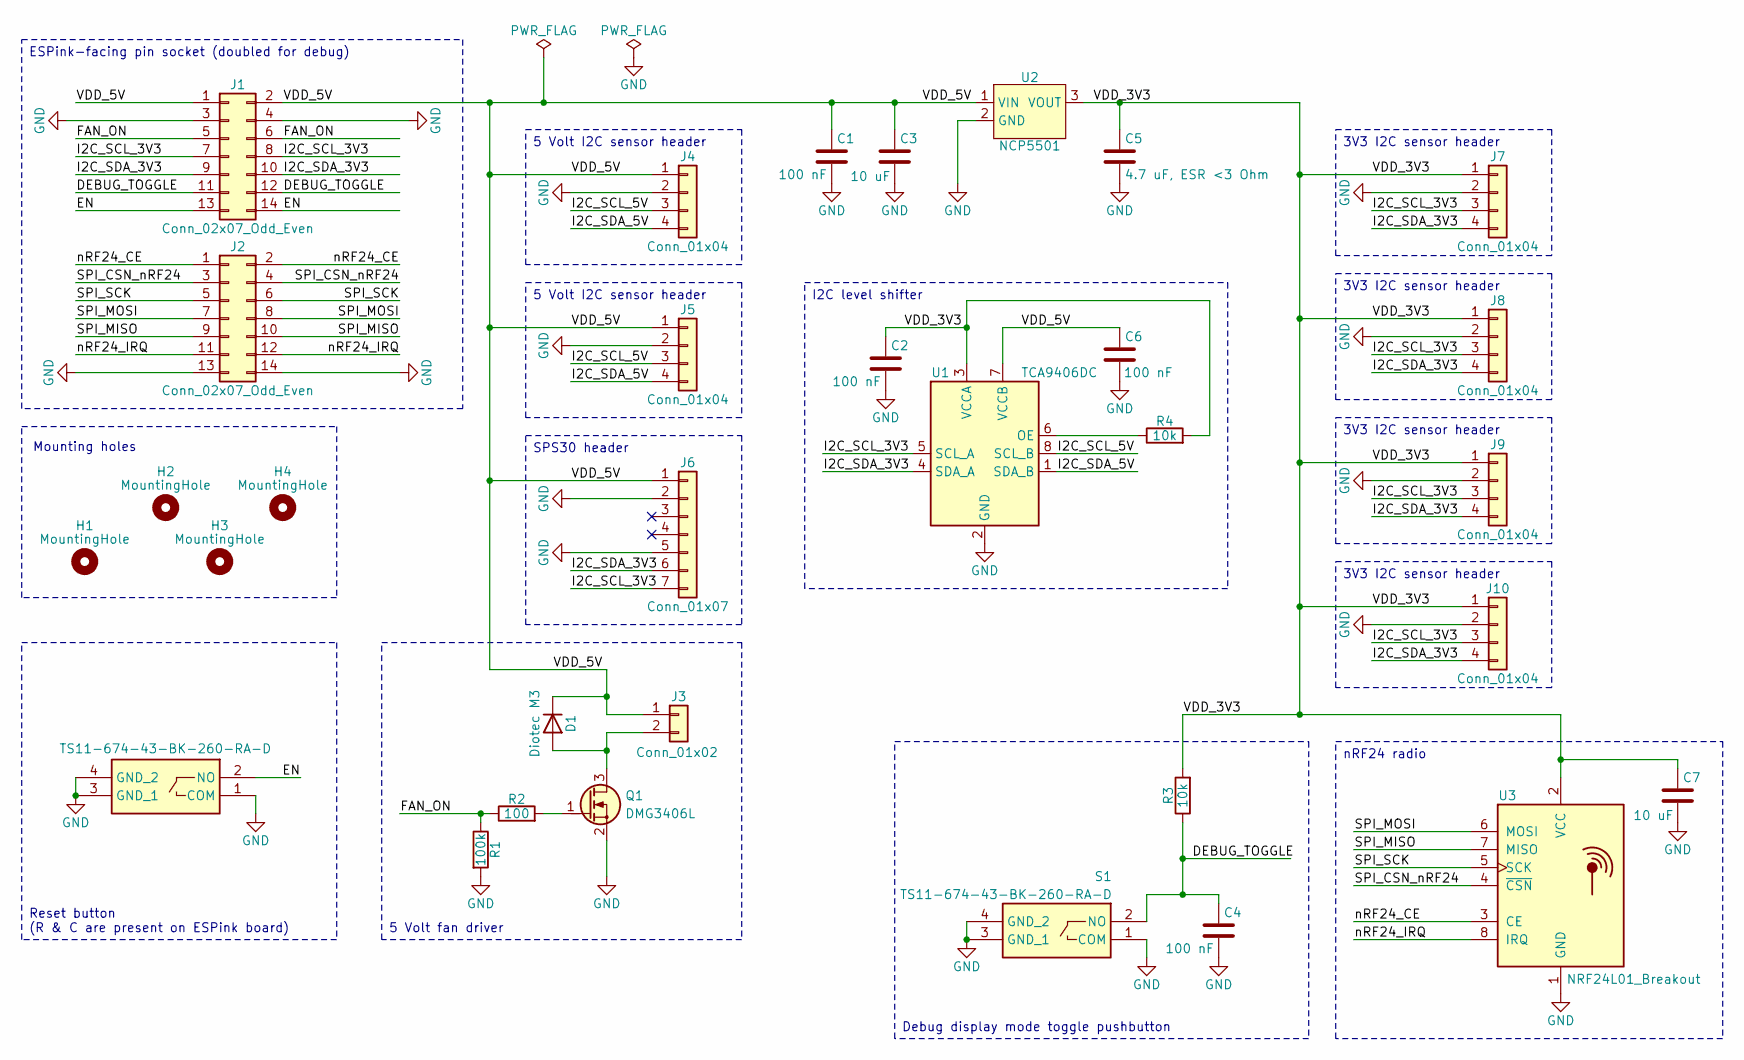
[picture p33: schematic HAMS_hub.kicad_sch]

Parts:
C1, C2, C4, C6: 100 nF; C_0805_2012Metric_Pad1.18x1.45mm_HandSolder
C3, C7: 10 uF; C_0805_2012Metric_Pad1.18x1.45mm_HandSolder
C5: 4.7 uF, ESR <3 Ohm; C_0805_2012Metric_Pad1.18x1.45mm_HandSolder
D1: Diotec M3; D_SMA_Handsoldering
H1, H2, H3, H4: MountingHole; MountingHole_2.2mm_M2_ISO7380
J1, J2: Conn_02x07_Odd_Even; PinSocket_2x07_P2.54mm_Vertical
J3: Conn_01x02; PinHeader_1x02_P2.54mm_Vertical
J4, J5, J7, J8, J9, J10: Conn_01x04; PinSocket_1x04_P2.54mm_Vertical
J6: Conn_01x07; PinHeader_1x07_P2.54mm_Vertical
Q1: DMG3406L; SOT-23
R1: 100k; R_0805_2012Metric_Pad1.20x1.40mm_HandSolder
R2: 100; R_0805_2012Metric_Pad1.20x1.40mm_HandSolder
R3, R4: 10k; R_0805_2012Metric_Pad1.20x1.40mm_HandSolder
S1, S2: TS11-674-43-BK-260-RA-D; TS1167443BK260RAD; Mouser Part Number 179-TS1167443260RAD
U1: TCA9406DC; SSOP-8_2.95x2.8mm_P0.65mm
U2: NCP5501; TO-252-2
U3: NRF24L01_Breakout; nRF24L01_Breakout

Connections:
/DEBUG_TOGGLE: C4.1, J1.11, J1.12, R3.1, S1.2 (NO)
/EN: J1.13, J1.14, S2.2 (NO)
/FAN_ON: J1.5, J1.6, R1.1, R2.1
/I2C_SCL_3V3: J1.7, J1.8, J6.7, J7.3, J8.3, J9.3, J10.3, U1.5 (SCL_A)
/I2C_SCL_5V: J4.3, J5.3, U1.8 (SCL_B)
/I2C_SDA_3V3: J1.9, J1.10, J6.6, J7.4, J8.4, J9.4, J10.4, U1.4 (SDA_A)
/I2C_SDA_5V: J4.4, J5.4, U1.1 (SDA_B)
/SPI_CSN_nRF24: J2.3, J2.4, U3.4 (~CSN)
/SPI_MISO: J2.9, J2.10, U3.7 (MISO)
/SPI_MOSI: J2.7, J2.8, U3.6 (MOSI)
/SPI_SCK: J2.5, J2.6, U3.5 (SCK)
/VDD_3V3: C2.1, C5.1, C7.1, J7.1, J8.1, J9.1, J10.1, R3.2, R4.2, U1.3 (VCCA), U2.3 (VOUT), U3.2 (VCC)
/VDD_5V: C1.1, C3.1, C6.1, D1.1 (K), J1.1, J1.2, J3.1, J4.1, J5.1, J6.1, U1.7 (VCCB), U2.1 (VIN)
/nRF24_CE: J2.1, J2.2, U3.3 (CE)
/nRF24_IRQ: J2.11, J2.12, U3.8 (IRQ)
GND: C1.2, C2.2, C3.2, C4.2, C5.2, C6.2, C7.2, J1.3, J1.4, J2.13, J2.14, J4.2, J5.2, J6.2, J6.5, J7.2, J8.2, J9.2, J10.2, Q1.2 (S), R1.2, S1.1 (COM), S1.3 (GND_1), S1.4 (GND_2), S2.1 (COM), S2.3 (GND_1), S2.4 (GND_2), U1.2 (GND), U2.2 (GND), U3.1 (GND)
unnamed: D1.2 (A), J3.2, Q1.3 (D)
unnamed: Q1.1 (G), R2.2
unnamed: R4.1, U1.6 (OE)

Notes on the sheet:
Mounting holes
Debug display mode toggle pushbutton
3V3 I2C sensor header
5 Volt I2C sensor header
5 Volt fan driver
ESPink-facing pin socket (doubled for debug)
nRF24 radio
I2C level shifter
SPS30 header
Reset button (R & C are present on ESPink board)

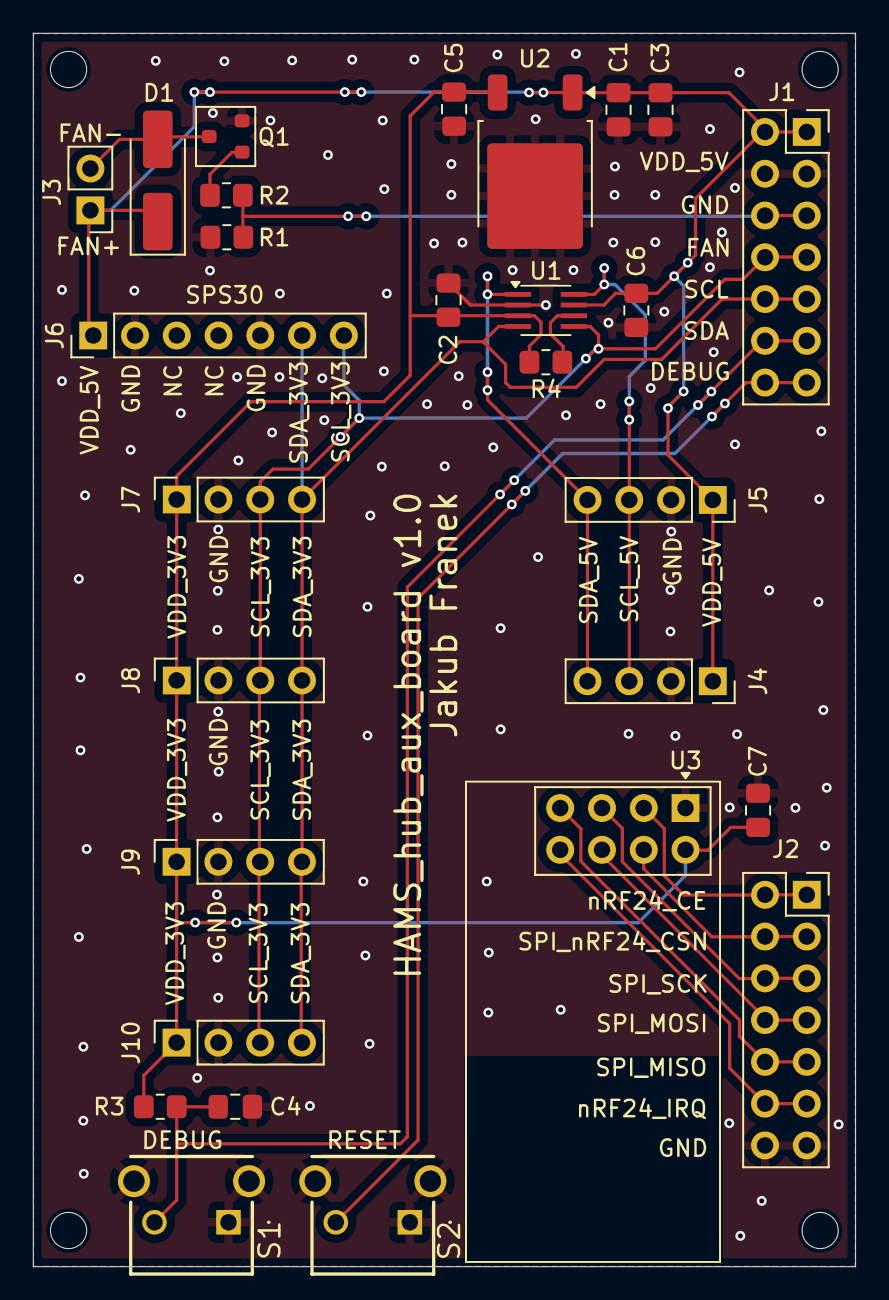
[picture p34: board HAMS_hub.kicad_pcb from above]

Board: 2 copper layers, 50.0 x 75.0 mm, 32 parts (0 on the bottom side), 19 nets.

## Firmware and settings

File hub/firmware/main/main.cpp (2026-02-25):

#include <stdio.h>
#include <time.h>
#include <sys/time.h>
#include <string.h>

#include "sdkconfig.h"
#include "freertos/FreeRTOS.h"
#include "freertos/task.h"
#include "esp_log.h"
#include "driver/gpio.h"

#include "hams_defines.h"
#include "display_control.h"
#include "wifi_station_control.h"
#include "sntp_control.h"
#include "sensor_control.h"
#include "radio_control.h"
#include "svatky_api.h"
#include "openweathermap_api.h"

#define LED_PIN GPIO_NUM_27
#define FAN_SWITCH_PIN GPIO_NUM_32
#define ESPINK_VSENSOR_ENA_PIN GPIO_NUM_2
#define BUTTON_DEBUG_PIN GPIO_NUM_36

#define NOTIFY_DISPLAY_UPDATE 1
#define NOTIFY_ENTER_DEBUG_MODE 2
#define NOTIFY_EXIT_DEBUG_MODE 3

extern "C"
{
    void app_main(void);
}

static const char *TAG = "main";

static int8_t status_code;

static SemaphoreHandle_t hams_data_mutex;
static HamsData hams_data;

static volatile bool debug_mode = false;
static volatile bool co2_schedule_calibration = false;

static TaskHandle_t task_handle_display_update;
static TaskHandle_t task_handle_nrf24_receive;
static TaskHandle_t task_handle_poll_button;

static void task_display_update(void *pvParameters);
static void task_poll_button(void *pvParameters);

static void update_display_data(void);
static void take_hams_data_mutex(void);
static void give_hams_data_mutex(void);

static void set_fan_state(bool on);
static void initialize_gpio(void);

/**
 * @brief Main entry point of the application.
 *
 * Initializes the hardware, sets up the tasks and enters the main loop.
 */
void app_main(void)
{
    hams_data_mutex = xSemaphoreCreateMutex();

    take_hams_data_mutex();

    initialize_gpio();
    setup_display();

    set_fan_state(true);

    print_line("GPIO & e-paper display initialized.\nFan turned on.\nInitializing Wi-Fi... ");
    status_code = setup_wifi();
    print_line("done (%d).\nInitializing SNTP... ", status_code);
    status_code = initialize_sntp();
    print_line("done (%d).\nInitializing timezone... ", status_code);
    setenv("TZ", "CET-1CEST,M3.5.0,M10.5.0/3", 1);
    tzset();
    print_line("done.\n");

    print_line("Requesting calendar data... ");
    status_code = request_calendar_data(&hams_data.calendar);
    print_line("done (%d).\nRequesting data from openweathermap.org... ", status_code);
    status_code = request_weather_data(&hams_data.weather);
    print_line("done (%d).\n", status_code);

    set_fan_state(false);
    print_line("Fan turned off.\n");

    print_line("Starting nRF24L01+ receiver task...");
    status_code = xTaskCreatePinnedToCore(task_nrf24_control, "nrf24_receive", 4096, NULL, 1, &task_handle_nrf24_receive, PRO_CPU_NUM);
    print_line("done (%d).\n", !status_code); // success = pdTRUE = 1, but HAMS convention is success = 0

    setup_sensors(true, &print_line);
    measure_sensors(true, &print_line);

    gettimeofday(&hams_data.debug.start_time, NULL);

    print_line("Clearing screen and entering main loop...\n");

    vTaskDelay(1000 / portTICK_PERIOD_MS); // Wait for 1 second to allow user to read the last message

    clear_screen();
    update_display_data();
    update_display(&hams_data);

    give_hams_data_mutex();

    xTaskCreatePinnedToCore(task_display_update, "display_update", 4096, NULL, 1, &task_handle_display_update, APP_CPU_NUM);
    xTaskCreatePinnedToCore(task_poll_button, "poll_button", 4096, NULL, 1, &task_handle_poll_button, APP_CPU_NUM);

    vTaskDelay(MAIN_LOOP_PERIOD_S * 1000 / portTICK_PERIOD_MS); // Wait to maintain interval between measurement/update cycles

    while (true) // Main loop
    {
        TickType_t xLastWakeTime = xTaskGetTickCount();

        set_fan_state(true);

        take_hams_data_mutex();

        if (!is_wifi_connected() && connect_wifi() == 0) // If Wi-Fi is not connected and connection is successful
        {
            synchronize_time(); // Forcefully synchronize time
        }

        request_calendar_data(&hams_data.calendar);
        request_weather_data(&hams_data.weather);

        give_hams_data_mutex();

        xTaskDelayUntil(&xLastWakeTime, FAN_TOGGLE_PERIOD_S * 1000 / portTICK_PERIOD_MS); // Wait until the fan period elapses
        set_fan_state(false);

        vTaskDelay(FAN_TOGGLE_PERIOD_S * 1000 / portTICK_PERIOD_MS); // Wait for 5 seconds after turning off the fan for sensors to stabilize

        if (co2_schedule_calibration)
        {
            schedule_co2_correction();
            co2_schedule_calibration = false;
        }
        measure_sensors(false, NULL); // Measure sensors without printing to the display

        take_hams_data_mutex();
        update_display_data();
        give_hams_data_mutex();

        xTaskNotify(task_handle_display_update, NOTIFY_DISPLAY_UPDATE, eSetValueWithOverwrite);

        xTaskDelayUntil(&xLastWakeTime, MAIN_LOOP_PERIOD_S * 1000 / portTICK_PERIOD_MS);
    }
}

/**
 * @brief Update the display with current data or switch to debug mode.
 *
 * This task waits for notifications from other tasks to update the display
 * with the current data or switch to debug mode. The notifications are
 * `NOTIFY_DISPLAY_UPDATE`, `NOTIFY_ENTER_DEBUG_MODE` and `NOTIFY_EXIT_DEBUG_MODE`.
 *
 * @param pvParameters Unused
 */
static void task_display_update(void *pvParameters)
{
    uint32_t notification;

    while (true)
    {
        notification = ulTaskNotifyTake(pdTRUE, portMAX_DELAY); // Wait for a notification from other tasks

        if ((notification == NOTIFY_DISPLAY_UPDATE) && !debug_mode)
        {
            ESP_LOGI(TAG, "NOTIFY_DISPLAY_UPDATE");
            take_hams_data_mutex();

            update_display(&hams_data);

            give_hams_data_mutex();
        }
        else if (notification == NOTIFY_ENTER_DEBUG_MODE && debug_mode)
        {
            ESP_LOGI(TAG, "NOTIFY_ENTER_DEBUG_MODE");
            take_hams_data_mutex();

            update_display_data();
            show_debug_info(&hams_data);

            give_hams_data_mutex();
        }
        else if (notification == NOTIFY_EXIT_DEBUG_MODE && !debug_mode)
        {
            ESP_LOGI(TAG, "NOTIFY_EXIT_DEBUG_MODE");
            take_hams_data_mutex();

            clear_screen();
            update_display_data();
            update_display(&hams_data);

            give_hams_data_mutex();
        }
    }
}

/**
 * @brief Poll the debug button and switch between display debug mode and normal mode.
 *
 * This task monitors the debug button and if it is pressed, it switches between
 * debug mode and normal mode of the display.
 */
static void task_poll_button(void *pvParameters)
{
    bool button_history[3] = {false, false, false};
    bool button_pressed = false;
    TickType_t t_loop = 0, t_button_press = 0, t_button_release = 0;
    uint32_t notification;

    while (true)
    {
        t_loop = xTaskGetTickCount();

        button_history[0] = button_history[1];
        button_history[1] = button_history[2];
        button_history[2] = !gpio_get_level(BUTTON_DEBUG_PIN);

        if (button_history[0] == false && button_history[1] == true && button_history[2] == true)
        {
            t_button_press = xTaskGetTickCount();
            button_pressed = true;
            ESP_LOGI(TAG, "Debug button pressed, ticks = %ld", t_button_press);
        }
        else if (button_pressed && button_history[0] == true && button_history[1] == false && button_history[2] == false)
        {
            t_button_release = xTaskGetTickCount();
            button_pressed = false;
            ESP_LOGI(TAG, "Debug button released, ticks = %ld", t_button_release);

            if ((t_button_release - t_button_press) < 2000 / portTICK_PERIOD_MS)
            {
                ESP_LOGI(TAG, "Debug button short press (%ld ticks), toggling debug mode", t_button_release - t_button_press);
                debug_mode = !debug_mode;
                notification = (debug_mode) ? NOTIFY_ENTER_DEBUG_MODE : NOTIFY_EXIT_DEBUG_MODE;
                xTaskNotify(task_handle_display_update, notification, eSetValueWithOverwrite);
            }
            else
            {
                ESP_LOGI(TAG, "Debug button long press (%ld ticks), scheduling SCD41 calibration", t_button_release - t_button_press);
                co2_schedule_calibration = true;
            }
        }

        xTaskDelayUntil(&t_loop, 100 / portTICK_PERIOD_MS); // Poll at 10 Hz
    }
}

/**
 * @brief Updates the display data structure with the latest information.
 *
 * This function fetches the latest Wi-Fi access point record and sensor hub data,
 * updates the node data, and synchronizes the SNTP last sync time and sync count.
 *
 * @warning This function is not thread-safe, taking the `hams_data_mutex` before
 * calling this is required.
 */
static void update_display_data(void)
{
    int8_t status = 0;

    // If any of the function calls returns any number other than zero, the status will be set to that number

    status = update_node_diagnostics() || status;
    status = (get_wifi_ap_record(&hams_data.debug) || status);
    status = (get_sensor_data(&hams_data.hub_sensors) || status);
    status = (get_node_data(hams_data.nodes) || status);
    status = (get_sntp_stats(&hams_data.debug.sntp_last_sync, &hams_data.debug.sntp_sync_count) || status);

    hams_data.debug.app_status = status;
}

/**
 * @brief Tries to take the hams_data_mutex semaphore.
 */
static void take_hams_data_mutex(void)
{
    if (xSemaphoreTake(hams_data_mutex, portMAX_DELAY) != pdPASS)
    {
        ESP_LOGE(TAG, "Failed to take hams_data_mutex, task = %s", pcTaskGetName(xTaskGetCurrentTaskHandle()));
        abort();
    }
    else
    {
        ESP_LOGD(TAG, "Taken hams_data_mutex, task = %s", pcTaskGetName(xTaskGetCurrentTaskHandle()));
    }
}

/**
 * @brief Releases the hams_data_mutex semaphore
 */
static void give_hams_data_mutex(void)
{
    ESP_LOGD(TAG, "Given hams_data_mutex, task = %s", pcTaskGetName(xTaskGetCurrentTaskHandle()));
    xSemaphoreGive(hams_data_mutex);
}

/**
 * @brief Set the state of the fan.
 *
 * @param on `true` to turn the fan on, `false` to turn it off.
 */
static void set_fan_state(bool on)
{
    ESP_ERROR_CHECK(gpio_set_level(FAN_SWITCH_PIN, (uint32_t)on));
    ESP_LOGI(TAG, "Fan turned %s", on ? "on" : "off");
}

/**
 * @brief Initializes the GPIO pins.
 *
 * Sets the GPIO pins to the following modes:
 *
 *  - `LED_PIN`: Output, floating pull mode, initially set to 0
 *
 *  - `FAN_SWITCH_PIN`: Output, floating pull mode, initially set to 0
 *
 *  - `ESPINK_VSENSOR_ENA_PIN`: Output, floating pull mode, initially set to 1
 *
 *  - `BUTTON_DEBUG_PIN`: Input, floating pull mode
 */
static void initialize_gpio(void)
{
    ESP_ERROR_CHECK(gpio_reset_pin(LED_PIN));
    ESP_ERROR_CHECK(gpio_set_direction(LED_PIN, GPIO_MODE_OUTPUT));
    ESP_ERROR_CHECK(gpio_set_pull_mode(LED_PIN, GPIO_FLOATING));
    ESP_ERROR_CHECK(gpio_set_level(LED_PIN, 0));

    ESP_ERROR_CHECK(gpio_reset_pin(FAN_SWITCH_PIN));
    ESP_ERROR_CHECK(gpio_set_direction(FAN_SWITCH_PIN, GPIO_MODE_OUTPUT));
    ESP_ERROR_CHECK(gpio_set_pull_mode(FAN_SWITCH_PIN, GPIO_FLOATING));
    ESP_ERROR_CHECK(gpio_set_level(FAN_SWITCH_PIN, 0));

    ESP_ERROR_CHECK(gpio_set_direction(ESPINK_VSENSOR_ENA_PIN, GPIO_MODE_OUTPUT));
    ESP_ERROR_CHECK(gpio_set_pull_mode(ESPINK_VSENSOR_ENA_PIN, GPIO_FLOATING));
    ESP_ERROR_CHECK(gpio_set_level(ESPINK_VSENSOR_ENA_PIN, 1));

    ESP_ERROR_CHECK(gpio_set_direction(BUTTON_DEBUG_PIN, GPIO_MODE_INPUT));
    ESP_ERROR_CHECK(gpio_set_pull_mode(BUTTON_DEBUG_PIN, GPIO_FLOATING));
}

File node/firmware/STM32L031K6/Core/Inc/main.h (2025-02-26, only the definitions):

#define LSE_IN_Pin LL_GPIO_PIN_14
#define LSE_IN_GPIO_Port GPIOC
#define LSE_OUT_Pin LL_GPIO_PIN_15
#define LSE_OUT_GPIO_Port GPIOC
#define BUTTON_LED_Pin LL_GPIO_PIN_4
#define BUTTON_LED_GPIO_Port GPIOA
#define BUTTON_LED_EXTI_IRQn EXTI4_15_IRQn
#define LED_ERROR_Pin LL_GPIO_PIN_6
#define LED_ERROR_GPIO_Port GPIOA
#define LED_STATUS_Pin LL_GPIO_PIN_7
#define LED_STATUS_GPIO_Port GPIOA
#define I2C_SCL_Pin LL_GPIO_PIN_9
#define I2C_SCL_GPIO_Port GPIOA
#define I2C_SDA_Pin LL_GPIO_PIN_10
#define I2C_SDA_GPIO_Port GPIOA
#define nRF24_IRQ_Pin LL_GPIO_PIN_15
#define nRF24_IRQ_GPIO_Port GPIOA
#define nRF24_IRQ_EXTI_IRQn EXTI4_15_IRQn
#define SPI_SCK_Pin LL_GPIO_PIN_3
#define SPI_SCK_GPIO_Port GPIOB
#define SPI_MISO_Pin LL_GPIO_PIN_4
#define SPI_MISO_GPIO_Port GPIOB
#define SPI_MOSI_Pin LL_GPIO_PIN_5
#define SPI_MOSI_GPIO_Port GPIOB
#define nRF24_CE_Pin LL_GPIO_PIN_6
#define nRF24_CE_GPIO_Port GPIOB
#define nRF24_CSN_Pin LL_GPIO_PIN_7
#define nRF24_CSN_GPIO_Port GPIOB
#define NVIC_PRIORITYGROUP_0         ((uint32_t)0x00000007) /*!< 0 bit  for pre-emption priority,
#define NVIC_PRIORITYGROUP_1         ((uint32_t)0x00000006) /*!< 1 bit  for pre-emption priority,
#define NVIC_PRIORITYGROUP_2         ((uint32_t)0x00000005) /*!< 2 bits for pre-emption priority,
#define NVIC_PRIORITYGROUP_3         ((uint32_t)0x00000004) /*!< 3 bits for pre-emption priority,
#define NVIC_PRIORITYGROUP_4         ((uint32_t)0x00000003) /*!< 4 bits for pre-emption priority,

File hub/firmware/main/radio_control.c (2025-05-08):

#include <stdio.h>
#include <time.h>
#include <sys/time.h>
#include <string.h>

#include "driver/gpio.h"
#include "driver/spi_master.h"
#include "freertos/FreeRTOS.h"
#include "esp_log.h"

#include "nrf24l01p.h"
#include "radio_control.h"
#include "node_constants.h"

#define NRF24_CE_PIN 25
#define NRF24_IRQ_PIN 26
#define NRF24_CSN_PIN 15

#define NRF24_PAYLOAD_LENGTH 10

static const char *TAG = "radio_control";

static void nrf24l01p_set_ce(uint8_t state);
static void nrf24l01p_set_cs(uint8_t state);
static int8_t nrf24l01p_spi_tx(const uint8_t *tx_data, uint8_t length);
static int8_t nrf24l01p_spi_rx(uint8_t *rx_data, uint8_t length);
static int8_t nrf24l01p_spi_tx_rx(const uint8_t *tx_data, uint8_t *rx_data, uint8_t length);
static void nrf24l01p_irq_handler(void *arg);
static int8_t decode_payload(uint8_t *payload);

static Nrf24l01pDevice nrf24_device = {
    .config = {
        .address_width = 5,
        .channel_MHz = 2500,
        .crc_length = NRF24L01P_CRC_1BYTE,
        .data_rate = NRF24L01P_250KBPS,
        .enable_irq_rx_dr = true,
        .enable_irq_max_rt = true,
        .enable_irq_tx_ds = true,
    },
    .rx_config = {
        .address_p0 = NODE0_ADDRESS,
        .address_p1 = NODE1_ADDRESS,
        .address_p2 = NODE2_ADDRESS,
        .address_p3 = NODE3_ADDRESS,
        .address_p4 = NODE4_ADDRESS,
        .address_p5 = NODE5_ADDRESS,
        .data_length = {
            NRF24_PAYLOAD_LENGTH,
            NRF24_PAYLOAD_LENGTH,
            NRF24_PAYLOAD_LENGTH,
            NRF24_PAYLOAD_LENGTH,
            NRF24_PAYLOAD_LENGTH,
            NRF24_PAYLOAD_LENGTH,
        },
        .auto_ack_pipes = 0b00111111,
        .enable_pipes = 0b00111111,
    },
    .tx_config = {
        .address = NRF24L01P_REG_TX_ADDR_RSTVAL,
        .auto_retransmit_count = 3,
        .auto_retransmit_delay_250us = 1,
        .output_power = NRF24L01P_0DBM,
    },
    .interface = {
        .set_cs = &nrf24l01p_set_cs,
        .spi_tx = &nrf24l01p_spi_tx,
        .spi_rx = &nrf24l01p_spi_rx,
        .spi_tx_rx = &nrf24l01p_spi_tx_rx,
    },
};
static Nrf24l01pStatus nrf24_status = NRF24L01P_SUCCESS;
static Nrf24l01pIrq nrf24_irq_sources = {
    .max_rt = false,
    .rx_dr = false,
    .tx_ds = false,
};
static volatile bool nrf24_irq_flag = false;
static bool rx_fifo_empty;
static uint8_t rx_payload[NRF24_PAYLOAD_LENGTH];

static SemaphoreHandle_t node_data_set_mutex; // Mutex for accessing `node_data_set`
static NodeData node_data_set[NODE_COUNT] = {
    {
        .node_name = NODE0_NAME,
        .node_id = 0,
    },
    {
        .node_name = NODE1_NAME,
        .node_id = 1,
    },
    {
        .node_name = NODE2_NAME,
        .node_id = 2,
    },
    {
        .node_name = NODE3_NAME,
        .node_id = 3,
    },
    {
        .node_name = NODE4_NAME,
        .node_id = 4,
    },
    {
        .node_name = NODE5_NAME,
        .node_id = 5,
    }};

static spi_bus_config_t spi_bus_config = {
    .mosi_io_num = 13,
    .miso_io_num = 12,
    .sclk_io_num = 14,
    .max_transfer_sz = 32,
    .flags = 0,
    .isr_cpu_id = APP_CPU_NUM,
    .intr_flags = 0,
};
static spi_device_interface_config_t nrf24_spi_device_config = {
    .command_bits = 0,
    .address_bits = 0,
    .dummy_bits = 0,
    .mode = 0,
    .clock_source = SPI_CLK_SRC_DEFAULT,
    .duty_cycle_pos = 128,
    .cs_ena_pretrans = 0,
    .cs_ena_posttrans = 0,
    .clock_speed_hz = 100000,
    .input_delay_ns = 0,
    .spics_io_num = NRF24_CSN_PIN,
    .flags = 0,
    .queue_size = 1,
    .pre_cb = NULL,
    .post_cb = NULL,
};
static spi_device_handle_t nrf24_spi_handle;

void task_nrf24_control(void *pvParameters)
{
    node_data_set_mutex = xSemaphoreCreateMutex();

    ESP_ERROR_CHECK(gpio_set_direction(NRF24_CE_PIN, GPIO_MODE_OUTPUT));
    ESP_ERROR_CHECK(gpio_set_pull_mode(NRF24_CE_PIN, GPIO_FLOATING));
    ESP_ERROR_CHECK(gpio_set_level(NRF24_CE_PIN, 0));

    ESP_ERROR_CHECK(gpio_set_direction(NRF24_CSN_PIN, GPIO_MODE_OUTPUT));
    ESP_ERROR_CHECK(gpio_set_pull_mode(NRF24_CSN_PIN, GPIO_FLOATING));
    ESP_ERROR_CHECK(gpio_set_level(NRF24_CSN_PIN, 1));

    ESP_ERROR_CHECK(gpio_set_direction(NRF24_IRQ_PIN, GPIO_MODE_INPUT));
    ESP_ERROR_CHECK(gpio_set_pull_mode(NRF24_IRQ_PIN, GPIO_FLOATING));
    ESP_ERROR_CHECK(gpio_intr_enable(NRF24_IRQ_PIN));
    ESP_ERROR_CHECK(gpio_set_intr_type(NRF24_IRQ_PIN, GPIO_INTR_NEGEDGE));
    ESP_ERROR_CHECK(gpio_install_isr_service(ESP_INTR_FLAG_LEVEL1));
    ESP_ERROR_CHECK(gpio_isr_handler_add(NRF24_IRQ_PIN, &nrf24l01p_irq_handler, (void *)NRF24_IRQ_PIN));

    ESP_ERROR_CHECK(spi_bus_initialize(SPI3_HOST, &spi_bus_config, SPI_DMA_DISABLED));
    ESP_ERROR_CHECK(spi_bus_add_device(SPI3_HOST, &nrf24_spi_device_config, &nrf24_spi_handle));

    nrf24_status = nrf24l01p_init_prx(&nrf24_device);
    ESP_LOGI(TAG, "init_prx: status = %d", nrf24_status);

    nrf24_status = nrf24l01p_clear_status_flags(&nrf24_device,
                                                (uint8_t)NRF24L01P_REG_STATUS_RX_DR |
                                                    NRF24L01P_REG_STATUS_TX_DS |
                                                    NRF24L01P_REG_STATUS_MAX_RT);
    ESP_LOGI(TAG, "clear_status_flags: status = %d", nrf24_status);

    nrf24_status = nrf24l01p_power_up(&nrf24_device);
    ESP_LOGI(TAG, "power_up: status = %d", nrf24_status);

    vTaskDelay(20 / portTICK_PERIOD_MS);

    nrf24l01p_set_ce(1);

    while (true)
    {
        vTaskDelay(10 / portTICK_PERIOD_MS);

        if (nrf24_irq_flag)
        {
            nrf24_irq_flag = false;

            nrf24_status = nrf24l01p_get_and_clear_irq_flags(&nrf24_device, &nrf24_irq_sources);
            ESP_LOGI(TAG, "irq flags: MAX_RT = %d, RX_DR = %d, TX_DS = %d, status = %d",
                     nrf24_irq_sources.max_rt, nrf24_irq_sources.rx_dr, nrf24_irq_sources.tx_ds, nrf24_status);

            if (nrf24_irq_sources.rx_dr)
            {
                while (true)
                {
                    nrf24_status = nrf24l01p_is_rx_fifo_empty(&nrf24_device, &rx_fifo_empty);
                    ESP_LOGI(TAG, "is_rx_fifo_empty = %d, status = %d", rx_fifo_empty, nrf24_status);

                    if (rx_fifo_empty)
                    {
                        break;
                    }

                    nrf24_status = nrf24l01p_rx_receive(&nrf24_device, rx_payload);
                    ESP_LOGI(TAG, "rx_receive: status = %d", nrf24_status);
                    decode_payload(rx_payload);
                }
            }
        }
    }
}

static void nrf24l01p_set_ce(uint8_t state)
{
    gpio_set_level(NRF24_CE_PIN, state);
}

static void nrf24l01p_set_cs(uint8_t state)
{
    // Leave empty, as CS is managed by ESP-IDF SPI driver
}
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

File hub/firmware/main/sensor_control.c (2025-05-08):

#include <stdio.h>
#include <string.h>

#include "driver/gpio.h"
#include "driver/i2c_master.h"
#include "freertos/FreeRTOS.h"
#include "esp_log.h"

#include "sht4x.h"
#include "sgp41.h"
#include "bme280_i2c.h"
#include "scd4x.h"
#include "sps30_i2c.h"

#include "hams_defines.h"
#include "sensor_control.h"

#define CO2_MEASUREMENT_MODULO CO2_MEASUREMENT_PERIOD_S / MAIN_LOOP_PERIOD_S
#define PM_MEASUREMENT_MODULO PM_MEASUREMENT_PERIOD_S / MAIN_LOOP_PERIOD_S

static const char *TAG = "sensor_control";

#define IF_TRUE(condition, statement) \
    if (condition)                    \
    {                                 \
        statement;                    \
    }

#define RETURN_IF_NOT_ZERO(status, data, error_counter) \
    data = status;                                      \
    if (status != 0)                                    \
    {                                                   \
        error_counter++;                                \
        return status;                                  \
    }

/* ---------- Static Prototypes ---------- */

static int8_t setup_i2c_bus(void);
static int8_t setup_sht4x(void);
static int8_t setup_sgp41(void);
static int8_t setup_bme280(void);
static int8_t setup_scd4x(void);
static int8_t setup_sps30(void);

static int8_t measure_sht4x(void);
static int8_t measure_sgp41(void);
static int8_t measure_bme280(void);
static int8_t measure_scd4x(void);
static int8_t measure_sps30(void);

static int8_t sht4x_i2c_write(uint8_t address, const uint8_t *payload, uint8_t length);
static int8_t sht4x_i2c_read(uint8_t address, uint8_t *payload, uint8_t length);
static int8_t sgp41_i2c_write(uint8_t address, const uint8_t *payload, uint8_t length);
static int8_t sgp41_i2c_read(uint8_t address, uint8_t *payload, uint8_t length);
static int8_t bme280_i2c_write(uint8_t address, const uint8_t *payload, uint8_t length);
static int8_t bme280_i2c_read(uint8_t address, uint8_t *payload, uint8_t length);
static int8_t scd4x_i2c_write(uint8_t address, const uint8_t *payload, size_t length);
static int8_t scd4x_i2c_read(uint8_t address, uint8_t *payload, size_t length);
static int8_t sps30_i2c_write(uint8_t address, const uint8_t *payload, uint8_t length);
static int8_t sps30_i2c_read(uint8_t address, uint8_t *payload, uint8_t length);
static int8_t delay_ms(uint16_t ms);

/* ---------- I2C ---------- */

static i2c_master_bus_handle_t bus;
static i2c_master_bus_config_t i2c_config = {
    .i2c_port = I2C_NUM_0,
    .sda_io_num = 21,
    .scl_io_num = 22,
    .clk_source = I2C_CLK_SRC_DEFAULT,
    .glitch_ignore_cnt = 7,
    .intr_priority = 1,
    .trans_queue_depth = 0};

/* ---------- SHT4x ---------- */

static i2c_device_config_t sht4x_config = {
    .dev_addr_length = I2C_ADDR_BIT_LEN_7,
    .device_address = SHT4X_I2C_ADDR_A,
    .scl_speed_hz = 100000,
    .scl_wait_us = 0};
static i2c_master_dev_handle_t sht4x_device_handle;

static Sht4xDevice sht4x_device = {
    .i2c_write = &sht4x_i2c_write,
    .i2c_read = &sht4x_i2c_read,
    .i2c_address = SHT4X_I2C_ADDR_A};
static Sht4xStatus sht4x_status;
static Sht4xData sht4x_data;
static uint32_t sht4x_serial_number;

/* ---------- SGP41 ---------- */

#define SGP41_SAMPLING_INTERVAL_S 60.0f

static i2c_device_config_t sgp41_config = {
    .dev_addr_length = I2C_ADDR_BIT_LEN_7,
    .device_address = SGP41_I2C_ADDRESS,
    .scl_speed_hz = 100000,
    .scl_wait_us = 0,
};
static i2c_master_dev_handle_t sgp41_device_handle;

static Sgp41Device sgp41_device = {
    .i2c_write = &sgp41_i2c_write,
    .i2c_read = &sgp41_i2c_read,
    .delay_ms = &delay_ms,
    .sampling_period_s = SGP41_SAMPLING_INTERVAL_S};
static uint64_t sgp41_serial_number;
static Sgp41Status sgp41_status;
static Sgp41Data sgp41_data;

/* ---------- BME280 ---------- */

static i2c_device_config_t bme280_config = {
    .dev_addr_length = I2C_ADDR_BIT_LEN_7,
    .device_address = BME280_I2C_ADDRESS_SDO_HIGH,
    .scl_speed_hz = 100000,
    .scl_wait_us = 0};
static i2c_master_dev_handle_t bme280_device_handle;

static Bme280Device bme280_device = {
    .i2c_write = &bme280_i2c_write,
    .i2c_read = &bme280_i2c_read,
    .address = BME280_I2C_ADDRESS_SDO_HIGH,
    .config = {
        .filter = BME280_FILTER_OFF,
        .spi_3wire_enable = false,
        .standby_time = BME280_STANDBY_TIME_0_5_MS,
        .temperature_oversampling = BME280_OVERSAMPLING_X1,
        .pressure_oversampling = BME280_OVERSAMPLING_X1,
        .humidity_oversampling = BME280_OVERSAMPLING_X1}};
static Bme280Status bme280_status;
static Bme280Data bme280_data;

/* ---------- SCD4x ---------- */

#define SCD4X_MAX_RETRY_COUNT 10
#define SCD4X_RETRY_PERIOD_MS 100

static i2c_device_config_t scd4x_config = {
    .dev_addr_length = I2C_ADDR_BIT_LEN_7,
    .device_address = SCD4X_I2C_ADDRESS,
    .scl_speed_hz = 100000,
    .scl_wait_us = 0};
static i2c_master_dev_handle_t scd4x_device_handle;

static Scd4xDevice scd4x_device = {
    .i2c_write = &scd4x_i2c_write,
    .i2c_read = &scd4x_i2c_read,
    .delay_ms = &delay_ms};
static Scd4xStatus scd4x_status;
static Scd4xData scd4x_data;
static bool scd4x_data_ready = false;
static uint64_t scd4x_serial_number;

/* ---------- SPS30 ---------- */

#define SPS30_MAX_RETRY_COUNT 10
#define SPS30_RETRY_PERIOD_MS 100

static i2c_device_config_t sps30_config = {
    .dev_addr_length = I2C_ADDR_BIT_LEN_7,
    .device_address = SPS30_I2C_ADDRESS,
    .scl_speed_hz = 100000,
    .scl_wait_us = 0};
static i2c_master_dev_handle_t sps30_device_handle;

static Sps30Device sps30_device = {
    .i2c_write = &sps30_i2c_write,
    .i2c_read = &sps30_i2c_read,
    .delay_ms = &delay_ms};
static Sps30Status sps30_status;
static Sps30FirmwareVersion sps30_version;
static char sps30_product_type[8] = {'\0'};
static char sps30_serial_number[32] = {'\0'};
static Sps30StatusFlags sps30_flags;
static Sps30FloatData sps30_float_data;
static bool sps30_data_ready = false;

/* ---------- Other static variables ---------- */

static HubSensorData sensor_hub_data;
static struct timeval current_time;

/* ---------- Functions ---------- */

static int8_t setup_i2c_bus(void)
{
    ESP_ERROR_CHECK(i2c_new_master_bus(&i2c_config, &bus));
    return 0;
}

static int8_t setup_sht4x(void)
{
    ESP_ERROR_CHECK(i2c_master_bus_add_device(bus, &sht4x_config, &sht4x_device_handle));

    sht4x_status = sht4x_request_serial_number(&sht4x_device);
    ESP_LOGI(TAG, "[SHT4x] Request Serial Number, status = %d", sht4x_status);
    RETURN_IF_NOT_ZERO((int8_t)sht4x_status, sensor_hub_data.temperature_humidity_status, sensor_hub_data.temperature_humidity_errors);

    vTaskDelay(20 / portTICK_PERIOD_MS);

    sht4x_status = sht4x_read_serial_number(&sht4x_device, &sht4x_serial_number);
    ESP_LOGI(TAG, "[SHT4x] Read Serial Number, serial number = %ld, status = %d", sht4x_serial_number, sht4x_status);
    RETURN_IF_NOT_ZERO((int8_t)sht4x_status, sensor_hub_data.temperature_humidity_status, sensor_hub_data.temperature_humidity_errors);

    return 0;
}
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

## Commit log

2024-11-07 Improve HAMS node FW: stop mode, bug fixes
    Improve stop mode current consumption (<1 uA reached).
    Add several pin user labels.
    Set unused pins to analog mode.
    Fix bug: incorrect I2C/SPI timeout logic.
    Fix bug: event flags cleared incorrectly in app.c.
    [HAMS node STM32L031K6.ioc, gpio_custom.c, main.h]
2024-11-08 Improve HAMS node FW: refactoring, bug fixes
    Add macros to make app.c code less repetitive.
    Disable LED pin (not used in final application).
    Fix bug: large stop mode current consumption (pins not set to analog
    mode).
    [HAMS node STM32L031K6.ioc, main.h]
2024-11-09 Improve HAMS node FW: f_CLK, sleep, SPI
    Lower clock from 32 MHz to 8 MHz.
    Increase I2C and SPI frequency 4x.
    Enter sleep mode when waiting for timer and nRF24 interrupts.
    Force nRF24_CE pin low during stop mode.
    Add SPI1_Transmit_Multi function optimized for transmitting multiple
    bytes in quick succession.
    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
2024-11-09 Improve HAMS node FW: optimize SPI, refactor
    Optimize SPI custom functions for speed.
    Make all SPI and I2C custom functions handle multi-byte transfers.
    Add const modifiers to relevant function signatures.
    Remove redundant status code returns from many functions.
2024-11-09 Improve HAMS node FW: ADC, app errors, refactoring
    Measure VDDA via ADC and send it via nRF24 in payload.
    Add more AppError enum members, modify error checking macros in app.c to
    use them.
    [HAMS node STM32L031K6.ioc, main.h]
2024-12-02 Improve HAMS node FW: fix bug, format, add TODO
    [nrf24l01p.h]
2024-12-18 Improve HAMS hub FW
    Move display functions to a separate file.
    Add custom memory partition table (code would not fit in default
    1 MB partition).
    Implement WiFi station module.
    Implement SNTP module.
    Implement svatkyAPI.cz module.
    Create reusable cjson_parsing module with helper functions.
    [partitions.csv]
2024-12-19 Improve HAMS hub FW: SHT4x & SGP41 sensors
    Add sensor_control module with support for SHT4x and SGP41 sensors.
    Add timeout to openweathermap_api request_weather_data function.
    Add timeout to svatky_api request_svatky_data function.
    Rename wifi_sta to wifi_station.
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2024-12-19 Improve HAMS hub FW: SCD41 sensor
    Add support for SCD41 sensor.
    Add Sgp41Device.sampling_period_s member.
2024-12-19 Improve HAMS hub FW: SPS30 sensor
    Add support for SPS30 sensor.
    Add delay function pointer to SGP41 driver to fix I2C errors.
    Merge sgp41_execute_self_test and sgp41_evaluate_self_test into one
    function.
    [main.cpp, sensor_control.c, sgp41.c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]
2024-12-19 Improve HAMS hub FW: SPS30 sensor
    Increase I2C function timeout periods to 20 ms.
    Add code to main.cpp to print formatted timezone-aware time.
2024-12-19 Improve HAMS hub FW: nRF24 receiver
    Implement nRF24 receiver code.
    Increase delay between SHT4x start measurement command and read
    measurement command to 20 ms to fix random I2C errors.
    [main.cpp, nrf24l01p.c, nrf24l01p.h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]
2024-12-19 Improve HAMS hub FW: refactor
    Add how-to guides to BME280 and nRF24 drivers.
    Move private nRF24 driver defines from .h to .c file.
2024-12-20 Improve HAMS hub FW: refactor display, sensor ctrl
    Add DisplayData and DebugData structs to display_control.
    Encapsulate sensor_control setup functions in a single setup_sensors
    Add SensorHubData struct.
    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
2024-12-20 Improve HAMS hub FW: fix bug, display real data
    Fix bug: radio_control function get_node_data does not copy data
    properly.
    Store hub's sensor data in SensorHubData struct.
    Show real data on e-ink display.
    [main.cpp, radio_control.c, sensor_control.c]
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2024-12-20 Improve HAMS hub FW: minor improvements
    Use current date in svatkyapi request.
    Request new weather forecast as soon as the date changes.
    Add display_control function docstrings.
    Fix bug: replace Czech characters in the nameday name.
    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
    [main.cpp]
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2024-12-21 Improve HAMS hub FW: improve debug mode
    Implement hub sensor error count debug mode values.
    Implement WiFi connection count debug mode value.
    [main.cpp, sensor_control.c]
2024-12-23 Improve HAMS hub FW: refactor, fix bugs
    Add calendar_data, hams_data and weather_data headers which
    include common struct definitions.
    Create DebugData struct, which is now a member of HamsData
    (previously DisplayData).
    Fix bug: rain and snow WeatherData members not reset to zero when their
    keys are not present in received JSON.
    Fix bug: SCD41 sensor error count not incremented when wait for data
    ready flag results in timeout.
    Fix bug: CO2 measurement considered timed-out too soon in
    display_control module.
    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
    [main.cpp]
2024-12-27 Improve HAMS hub FW: refactor, fix bugs
    Merge redundant delay functions in sensor_control.
    Fix bug: SPS30 error count not incremented upon timeout.
    Move common application level defines to hams_defines.
    [main.cpp, sensor_control.c]
2024-12-27 Improve HAMS hub FW: refactor
    Add & improve comments/docstrings in multiple files.
    Rename nodes.h/c to node_constants.h/c.
    Rename sntp_api to sntp_control.
    Add get_sntp_stats function to sntp_api.
    Rename wifi_station to wifi_station_control.
    Add logging, connection counting, error checking to
    wifi_station_control.
    Add logic to svatky_api and openweathermap_api which determines
    whether to request new data.
    Add setup_sensors and measure_sensors functions to sensor_control.
    Encapsulate some code within main to functions.
    [bme280_i2c.c, main.cpp, radio_control.c]
2024-12-27 Improve HAMS hub FW: fix bug, utilize second CPU
    Fix bug: typical particulate matter particle size unit is nm, but
    should be um.
    Run task_nrf24_control on second core (PRO_CPU).
    [main.cpp, radio_control.c]
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2024-12-29 Add SHT40 burn-in PlatformIO utility project
    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
    [main.cpp]
2024-12-29 Add HAMS node HW KiCad files (WIP)
    HAMS node schematic is work-in-progress.
    [HAMS_node.kicad_pcb, HAMS_node.kicad_sch]
2024-12-30 Improve SHT40 calibration utility project
    Toggle MOSFET to draw more current periodically in order to prevent
    power bank from switching off.
    [main.cpp]
2024-12-30 Improve HAMS node HW: add WIP PCB, edit schematic
    Update schematic significantly (adding nRF24 modules, specify parts, add
    notes etc).
    Add preliminary PCB layout (WIP).
    [HAMS_node.kicad_pcb, HAMS_node.kicad_sch]
2024-12-30 Improve HAMS node HW: PCB and device resize
    Change many 0805 devices for 0603 devices.
    Add mounting holes.
    Make the board 4.5 x 5 cm size.
    [HAMS_node.kicad_pcb, HAMS_node.kicad_sch]
2025-01-04 Improve HAMS node HW: PCB resize, optimization
    Optimize MCU pinout with respect to PCB routing.
    Change PCB size to 47.5 mm x 50 mm.
    [HAMS_node.kicad_pcb, HAMS_node.kicad_sch]
2025-01-05 Improve HAMS node HW: schematic and PCB
    Change LED section (compact LED, DPDT switch).
    Remove VDDA ferrite bead and bulk capacitor.
    Add pads for I2C pullups.
    Add silkscreen labels.
    Update footprints of custom symbols.
    Change mounting holes to non-grounded.
    [HAMS_node.kicad_pcb, HAMS_node.kicad_sch]
2025-01-08 Improve HAMS node HW: schematic and PCB
    Add UART support to the ST-LINK programmer header.
    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
    [HAMS_node.kicad_pcb, HAMS_node.kicad_sch]
2025-01-15 Improve HAMS node HW: PCB
    Update HAMS_node PCB layout (minor position changes).
    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
    [HAMS_node.kicad_pcb]
2025-01-15 Improve HAMS hub FW: fix bug
    Fix bug: error codes printed in debug messages are unrelated to the
    given sensors.
    [sensor_control.c]
2025-01-15 Add HAMS hub HW KiCad files (WIP)
    HAMS hub schematic is work-in-progress.
    [HAMS_hub.kicad_pcb, HAMS_hub.kicad_sch, HAMS_node.kicad_pcb]
2025-01-17 Improve HAMS hub HW: schematic and PCB
    Improve schematic (add debug headers and mounting holes).
    Add DRC-clean PCB design.
    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
    [HAMS_hub.kicad_pcb, HAMS_hub.kicad_sch]
2025-01-18 Improve HAMS hub & node HW: schematic and PCB
    Finalize hub and node PCB layouts & schematics.
    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
    [HAMS_hub.kicad_pcb, HAMS_hub.kicad_sch, HAMS_node.kicad_pcb]
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2025-01-27 Improve HAMS hub HW: reset button
    Add reset button.
    [HAMS_hub.kicad_pcb, HAMS_hub.kicad_sch]
2025-01-27 Improve HAMS hub HW: status button rework
    Replace toggle switch with tactile switch for status button.
    [HAMS_node.kicad_pcb, HAMS_node.kicad_sch]
2025-01-30 Improve HAMS node & hub HW: PCB update
    [HAMS_hub.kicad_pcb, HAMS_hub.kicad_sch, HAMS_node.kicad_pcb]
2025-01-30 Add HAMS node & hub PCB gerbers
    [HAMS_hub-B_Cu.gbl, HAMS_hub-B_Mask.gbs, HAMS_hub-B_Paste.gbp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]
2025-02-08 Add HAMS node & hub 3D models, update task list
    Update .gitignore.
    Add HAMS hub and node PCB 3D models.
    Add HAMS hub case 3D model.
    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
    [HAMS_hub.step, HAMS_hub_case.3mf, HAMS_hub_cover.stl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]
2025-02-12 Update README and task list
    [HAMS_node.kicad_sch]
2025-02-26 Update KiCAD files to version 9
    [HAMS_hub.kicad_pcb, HAMS_hub.kicad_sch, HAMS_node.kicad_pcb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]
2025-02-26 Improve HAMS node FW: UART, current fix, init fix
    Add UART debug statements to app.c file.
    Fix bug where sleep current was too large due to incorrect GPIO setting
    in sleep mode (nRF24_CE, nRF24_CSN, SPI_SCK and SPI_MOSI should not be
    high-Z).
    Fix bug where important app state variables (event, state, app_status,
    leds_on and button_pending) were not initialized properly.
    [HAMS node STM32L031K6.ioc, gpio_custom.c, main.h]
2025-02-26 Improve HAMS node FW: update nRF24 driver (bugged)
    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
    [nrf24l01p.c, nrf24l01p.h]
2025-02-26 Improve HAMS node FW: fix nRF24 bug
    Fix bugged nRF24 by adding missing IRQ mask values when initializing
    nRF24 struct.
    Make leds_on and button_pending variables boolean.
2025-03-01 Improve HAMS node FW: fix bugs, refactor UART logs
    Fix bug: incorrect auto retransmit delay calculation.
    Refactor UART debug logging and debug mode (previously leds_on).
    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
2025-03-01 Improve HAMS node HW & FW
    Add HAMS node small case 3D printing files.
    Update SHT4x driver in HAMS node firmware.
    Add comments and docstrings to HAMS node firmware.
    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
    [HAMS_node_case_small.3mf, HAMS_node_case_small.stl, HAMS_node_case_small_cover.stl]
2025-03-01 Update HAMS node and hub 3D printing files
    [HAMS_hub_case_cut.3mf, HAMS_node_case_small.3mf]
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2025-03-05 Update 3D printing files
    [HAMS_hub_case.3mf, HAMS_hub_cover.3mf, HAMS_hub_cover.stl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]
2025-03-16 Update hub FW
    Rotate display to match enclosure orientation.
    Make 24h temperature minimum display optional and disable it.
    Add SCD41 FRC correction factor value to debug mode display.
    Simplify node info in debug display.
    Add code to allow SPS30 measurements at different rates (currently still
    1 minute).
    Add SCD41 FRC scheduling capability to debug mode button.
    Rename nodes.
    Fix bug: SCD4x driver I2C commands have incorrect length.
    Fix bug: measure_sensors function returning incorrect variable.
    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
    [main.cpp, scd4x.c, sensor_control.c]
2025-03-16 Improve HAMS node & hub FW, fix bugs
    Set node and hub nRF24 data rate to 250 kbps.
    Fix bug: incorrect register bit field position values in nRF24 driver
    header.
    Fix bug: incorrect atmospheric pressure units.
    Rename node "Detsky pok." to "Detsky pokoj".
    Shorten node debug mode text.
    [nrf24l01p.h, radio_control.c, sensor_control.c]
2025-03-17 Add 3D printing files, update task list
    [HAMS_node_case_small_x2.3mf]
2025-03-17 Remove redundant 3D printing files
    [HAMS_hub_case_cut.3mf]
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2025-05-08 Improve hub debug, add hub temperature correction
    Add hub temperature correction factor.
    Add new node transmission diagnostic quantities to hub debug mode.
    Remove node specific 24h temperature minimum quantity from codebase.
    [main.cpp, radio_control.c, sensor_control.c]
2025-05-08 Improve HAMS node FW: bug fix, slow down TIM21
    Slow down TIM21 by a factor of 10 (from 1 us to 10 us period),
    to allow scheduling interrupts for later.
    Fix bug: app_status not assigned in handle_state_awaiting_ack function
    when nRF24 IRQ times out.
    Fix bug: nRF24 IRQ flags not cleared at the start of cycle.
    [HAMS node STM32L031K6.ioc]

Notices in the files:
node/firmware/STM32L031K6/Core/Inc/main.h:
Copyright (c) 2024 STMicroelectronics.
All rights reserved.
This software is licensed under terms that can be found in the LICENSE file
